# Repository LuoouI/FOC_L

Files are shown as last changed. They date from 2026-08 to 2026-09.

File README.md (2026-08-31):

# CYT

整套 CYT2BL3 FOC 电机驱动工程。

- `CYT/FOC_L/`：固件源码和底层工程
- `CYT/上位机/`：电机调试上位机
- `CYT/PCB/`：PCB 工程
- `CYT/电机调试台/`：调试台结构件
- `CYT/数据手册/`：芯片数据手册
- `CYT/上位机讲解视频/`：上位机讲解视频及在线播放地址

当前为开源实验版本。

项目采用 MIT License，第三方 SDK 和底层库仍遵循其各自许可证。

## 上位机讲解视频

[哔哩哔哩在线观看：基于 CYT2BL3 FOC 电机驱动项目开源，包含完整驱动代码、PCB、上位机、电机调试台、数据手册及讲解视频](https://www.bilibili.com/video/BV14Ytx69EH2)

[下载仓库中的上位机讲解原始视频](CYT/上位机讲解视频/上位机讲解%20.mp4)

## 电机调试台

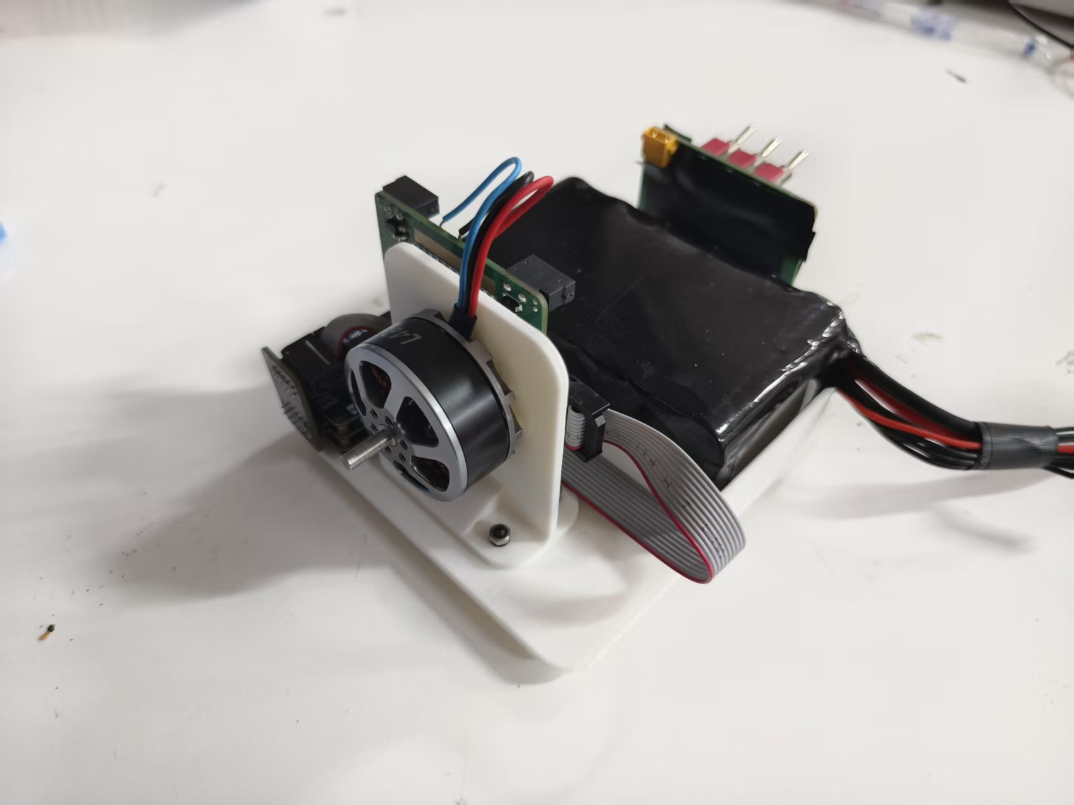
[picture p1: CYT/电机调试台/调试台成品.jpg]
电机调试台成品


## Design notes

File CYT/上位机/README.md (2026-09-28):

# FOC_L

用于当前 `FOC_L` 工程的 Windows 电机调试上位机。首版提供完整的仿真设备，可在下位机通信协议完成前检查工作流和界面。

## 已完成功能

- 电机连接、使能、停止、急停和急停复位
- 驱动板软件复位并自动重新同步设备参数
- 电压、电流/转矩、速度、位置四种控制模式
- 无感 FOC 的 HFI、SMO、PLL 参数分组，HFI 暂留，SMO/PLL 参数可在线调节
- 电流环、速度环、位置环和 SMO/PLL 使用可调边界滑块在线调参，滑块左右边界支持断电保存
- 开环、电流和速度目标使用可调边界滑块，位置目标使用首尾相接的圆盘实时给定，圆盘将 0° 与 360° 作为同一点，目标滑块边界支持断电保存
- 转速、电流、电压、角度、温度、PWM 等实时状态
- SMO 实际/估算 Iα、Iβ、Iq 误差、反电动势与 PLL 角度、角速度、相位误差示波器通道
- 示波器目标机械角度观测通道，可与实际机械角度对比
- 50000 点/通道环形缓冲示波器、按勾选通道订阅高速流、可见区峰谷抽稀、双点时间差测量、暂停显示和 CSV 导出
- 左侧菜单独立切换实时工作台和串口诊断
- Windows COM 口扫描、串口配置、协议帧过滤与手动发送
- 选择下位机内置乐曲并通过圆形播放按钮启动，播放完成后自动停止
- 事件和故障操作日志
- 控制、示波器和通道窗口根据可用空间自动调整尺寸，同时保留拖拽调整
- `Ctrl + +` 放大界面，`Ctrl + -` 缩小界面

## 启动

首次运行：

```powershell
cd "CYT\上位机"
npm install
npm run build
npm start
```

开发模式：

```powershell
npm run dev
```

仅在浏览器中预览界面：

```powershell
npm run dev:web
```

## 教学视频

上位机安装、串口连接和参数调试教学视频正在制作中，发布后补充链接。

## 当前限制

上位机通过 USB 转串口连接电机驱动板，CAN 留给 MCU 之间通信。串口协议实现位于 `electron/serial/protocol.cjs`，协议说明见 `docs/SERIAL_PROTOCOL.md`。当前下位机复用 `debug_init()` 的 UART0（460800 bit/s、P00_1/P00_0），连接期间不要在该串口输出 `printf` 文本。示波器全部已勾选设备通道固定 1 ms 采样，包括实际转速、实际 Iq、母线电压和机械角度；下位机在同一采样点读取所选字段，不再按字段数量自动降低采样率。当前波特率和 80% 带宽预算下最多允许同时勾选 8 个设备通道，超额选择或带宽不足的串口配置修改会被拒绝并提示。连接有效时电机失能仍保持采样，控制通信超时才暂停观测流。需要同步更新下位机固件；基础遥测仅更新状态卡，不作为已选设备通道的低速波形回退。

`foc_voice` 音乐模式负责选择下位机内置乐曲并发送播放命令。乐曲节拍和实际播放均由下位机负责；播放会话号用于防止 20 Hz 控制心跳重复触发歌曲，播放状态位用于在乐曲结束后自动关闭上位机使能。

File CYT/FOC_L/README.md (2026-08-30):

# FOC_L 固件

基于 CYT2BL3 的三相无刷电机 FOC 控制固件，包含电流环、速度环、位置环、SVPWM、电流采样、编码器反馈、参数存储和上位机通信。

## 目录

- `.vscode/`：IAR VS Code 辅助配置
- `libraries/`：CYT2BL3 SDK 和逐飞底层库
- `project/code/`：FOC、电机控制、采样、滤波和通信代码
- `project/user/`：主函数和中断入口
- `project/iar/`：IAR 工程配置

## 开发环境

- MCU：CYT2BL3
- IDE：IAR Embedded Workbench 9.40.1
- 工程入口：`project/iar/cyt2bl3.eww`

## 相关文档

- 固件模块说明：`project/code/驱动代码说明.md`
- 零点校准与三相自检提示音：`project/code/零点校准与三相自检提示音.md`
- TCPWM 和 ADC 触发链路：`project/code/FOC_TCPWM触发ADC采样链路.md`
- TCPWM、TriggerMux、ADC 术语：`project/code/FOC_TCPWM_ADC名词解释.md`

## 注意事项

本固件为个人实验和开发版本。首次上电应使用限流电源并进行空载测试，使用者需要根据实际功率器件和硬件设计确认过流、过压、欠压、过温及急停保护。

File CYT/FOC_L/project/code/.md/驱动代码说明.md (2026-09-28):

# CYT2BL3 FOC 电机驱动代码说明

## 1. 项目简介

本目录为基于 CYT2BL3 微控制器的三相无刷电机 FOC 驱动代码，主要用于电机控制算法验证、硬件调试和上位机联调。

当前代码包含以下功能：

- SVPWM 三相 PWM 输出
- Clarke/Park 变换及反变换
- 电流环、速度环和位置环控制
- 编码器角度采集、方向修正和零点校准
- ADC 电流采样及采样值校准
- 串口控制协议和运行状态回传
- 电机参数 Flash 保存
- 基于 FOC 的音乐播放实验功能

本项目当前属于实验和开发版本，使用前应先进行限流供电、空载测试和急停测试。

## 2. 目录结构

| 目录或文件 | 作用 |
|---|---|
| `Current_sample/` | 电流采样、采样值处理和校准 |
| `Fast_sin/` | 快速正弦和余弦计算 |
| `Filter/` | 滑动滤波器、AB 滤波器 |
| `Foc_transform/` | Clarke、Park 及反变换 |
| `Foc_Protocol/` | 上位机通信协议、帧解析和状态回传 |
| `Foc_voice/` | FOC 音乐模式和曲目播放 |
| `Function/` | 通用数学和辅助函数 |
| `Motor_Control/` | 电机状态机、三环控制和使能控制 |
| `Motor_Flash/` | 电机参数的 Flash 读写 |
| `Motor_Torque/` | 电流到估算转矩的换算 |
| `My_ADC/` | ADC 和触发链路初始化 |
| `My_TCPWM/` | PWM、TCPWM 和 ADC 触发配置 |
| `My_Key/` | 按键输入处理 |
| `My_LED/` | LED 状态指示 |
| `PID/` | PID 控制器实现 |
| `SVPWM/` | SVPWM 占空比计算和输出更新 |
| `My_Headfile.h` | 工程模块统一头文件 |
| `../user/main_cm4.c` | CM4 主函数和系统初始化 |
| `../user/cm4_isr.c` | CM4 中断服务函数 |

## 3. 控制流程

系统启动后，主函数依次完成 GPIO、ADC、TCPWM、PWM、编码器、Flash 参数和通信模块初始化。

电机运行时，PWM 中断负责高速控制任务：

1. 读取 ADC 电流采样值。
2. 进行电流偏置修正和坐标变换。
3. 执行电流环 PI 控制。
4. 根据控制模式执行速度环或位置环。
5. 计算电压矢量并生成 SVPWM 占空比。
6. 更新三相 PWM 输出和运行状态缓存。

通信接收和参数处理在较低优先级的主循环中执行，避免在高速控制中断中进行阻塞操作。

## 4. 控制模式

当前协议支持以下驱动模式：

| 模式 | 说明 |
|---|---|
| 开环模式 | 直接控制电压和电角度，适合初步检查相序和硬件输出 |
| 编码器 FOC | 使用编码器反馈进行电流、速度或位置控制 |
| 音乐模式 | 使用 FOC 产生设定频率和幅值的旋转磁场 |

有感 FOC 启动前应确认编码器方向、零点偏移、电流采样极性和电机相序均正确。

## 5. 参数说明

主要控制参数位于 `Motor_Control` 和 `Foc_Protocol` 模块中，包括：

- 电流环带宽
- 速度环 KP、KI
- 速度目标和速度斜坡
- 位置环 KP
- 位置角度死区和速度死区
- 位置环输出限幅
- AB 滤波器带宽
- 编码器零点偏移

电流环、速度环、位置环和观测器运行参数支持在线调整，下位机完成范围检查后在短临界区内整组应用。PWM 频率、死区和电机基础参数等硬件相关配置仍应在电机失能状态下修改；需要长期保存的参数应另行写入 Flash。

## 6. 通信接口

上位机默认通过 UART 连接驱动板，串口参数为：

- 波特率：460800 bit/s
- 数据位：8
- 校验位：无
- 停止位：1
- 多字节数据：小端序
- 浮点数：IEEE 754 单精度

完整帧格式和负载定义见上位机目录中的 `docs/SERIAL_PROTOCOL.md`。

控制帧包含使能、急停、控制模式、目标值和参数等信息。连续一段时间未收到合法控制帧时，驱动应关闭 PWM 输出。急停状态的优先级高于普通控制命令。

## 7. 调试建议

建议按照以下顺序进行调试：

1. 不连接电机，确认芯片能够正常启动和下载。
2. 检查三相 PWM 波形、频率、互补关系和死区时间。
3. 检查 ADC 触发时刻和电流采样偏置。
4. 低压限流条件下进行开环低幅值测试。
5. 检查编码器计数方向和机械角度变化。
6. 执行编码器零点校准。
7. 先调电流环，再调速度环，最后调位置环。
8. 逐步提高母线电压和目标转速。

## 8. 安全注意事项

- 首次上电必须使用限流电源，禁止直接接入未经确认的高压母线。
- 电机运行时应确保转子和负载不会造成人身伤害。
- 急停功能必须在实际硬件上验证，不能只依赖上位机按钮。
- 电流采样极性、编码器方向或电机相序错误时，不得继续提高电压和电流。
- 本代码未声明适用于人身安全、汽车、航空或其他安全关键设备。
- 使用者需要根据自己的功率器件、栅极驱动器和电源结构补充过流、过压、欠压、过温和硬件关断保护。

## 9. 当前限制

- 工程依赖对应芯片 SDK 和第三方底层库，具体版本需要根据本地开发环境配置。
- 当前目录主要保存控制源码，完整 IDE 工程配置和生成文件可能未随源码发布。
- 不同电机、电流采样电路和编码器需要重新校准参数。
- 参数默认值仅用于当前实验硬件，不代表通用电机配置。
- 代码和通信协议仍可能发生变化，当前版本不保证向后兼容。

## 10. 开源说明

本代码仅供学习、研究和实验使用。使用、修改或分发前，请分别确认芯片 SDK、底层库、示例代码和其他第三方文件的授权范围。项目许可证以仓库根目录中的 `LICENSE` 文件为准。

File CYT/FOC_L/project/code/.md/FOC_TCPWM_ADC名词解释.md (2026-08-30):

# CYT2BL3 FOC：TCPWM、TriggerMux 与 ADC 名词解释

## 1. 整体理解

在本工程中，各模块的分工可以先这样理解：

```text
TCPWM：决定什么时候采样
TriggerMux：决定触发信号送到哪里
PASS：管理模拟输入、ADC 和 ADC 触发
SAR：真正完成模拟量采样和模数转换
ADC 中断：通知 CPU 数据已经转换完成
```

可以把它类比成：

```text
TCPWM            = 闹钟
tr_out1          = 闹钟输出线
TriggerMux       = 电话交换机
PASS Generic0    = 广播频道
SAR0/SAR1/SAR2   = 三台 ADC 转换机器
ADC Channel      = 每台机器需要采集的具体输入
Group Done       = 本次采集任务全部完成的通知
```

完整链路为：

```text
TCPWM CC1 Match
    ↓
TCPWM tr_out1
    ↓
PERI TriggerMux
    ↓
PASS Generic Trigger
    ↓
SAR ADC Channel
    ↓
采样和转换
    ↓
Group Done
    ↓
FOC 电流环
```

---

## 2. 三种不同的 Group

这里出现了三种完全不同的 Group，不能混为一谈。

### 2.1 TCPWM Group

表示 TCPWM 计数器的硬件分组：

| TCPWM Group | 功能 |
| --- | --- |
| Group0 | 普通 16 位定时器组 |
| Group1 | 带电机控制功能的 16 位定时器组 |
| Group2 | 32 位定时器组 |

FOC 一般优先使用 Group1。

### 2.2 TriggerMux Group

表示触发路由硬件的分组。每组支持的触发来源和目标不同。

当前方案使用 TriggerMux Group6，是因为该组可以选择 TCPWM Group1 的 `tr_out1`，并把它送到 PASS 通用触发输入。

### 2.3 ADC Group

表示一次 ADC 触发后需要顺序转换的一组通道。

例如同一个 SAR 顺序采集三个通道：

```text
CH0：组首，直接接收硬件触发
CH1：不直接接收硬件触发
CH2：组尾，转换完成后产生 Group Done
```

三种 Group 之间没有编号对应关系。

---

## 3. TCPWM

TCPWM 可以理解为 Timer、Counter、PWM 的组合外设。

它可以完成：

- 定时
- 计数
- PWM 输出
- 编码器计数
- 输入捕获
- 产生其他外设的硬件触发

在 FOC 中，TCPWM 主要负责：

```text
1. 产生 U、V、W 三相互补 PWM
2. 在指定 PWM 位置触发 ADC
```

---

## 4. TCPWM0_GRP1_CNT0

```c
TCPWM0_GRP1_CNT0
```

拆开理解：

```text
TCPWM0：第 0 个 TCPWM 外设
GRP1：TCPWM 的电机控制计数器组
CNT0：Group1 中第 0 个计数器
```

FOC 三相 PWM 可以使用：

```text
TCPWM0_GRP1_CNT0：U 相
TCPWM0_GRP1_CNT1：V 相
TCPWM0_GRP1_CNT2：W 相
```

三个计数器必须同步计数和同步启动。

---

## 5. COUNTER

`COUNTER` 是计数器当前值。

中心对齐 PWM 的计数过程为：

```text
0 → PERIOD → 0 → PERIOD → 0
```

例如：

```text
PERIOD = 4000
```

计数过程为：

```text
0, 1, 2 ... 3999, 4000, 3999 ... 2, 1, 0
```

一次向上计数加一次向下计数，构成一个完整的中心对齐 PWM 周期。

---

## 6. PERIOD

`PERIOD` 是计数器的顶部值。

中心对齐 PWM 频率近似为：

```text
PWM 频率 = TCPWM 计数时钟 / (2 × PERIOD)
```

实际计算还需要考虑：

- TCPWM 输入时钟
- TCPWM 内部分频器
- PERIOD 是否包含计数端点

---

## 7. CC0 与 CC1

`CC` 表示 Compare/Capture，即比较/捕获寄存器。

PWM 模式主要使用比较功能。

### 7.1 CC0

`CC0` 通常控制 PWM 占空比。

```text
COUNTER == CC0
        ↓
产生 CC0 Match
        ↓
根据 TR_PWM_CTRL 改变 PWM 输出
```

在 FOC 中：

```text
U 相 CC0：U 相占空比
V 相 CC0：V 相占空比
W 相 CC0：W 相占空比
```

SVPWM 最终计算的就是三个 CC0 值。

### 7.2 CC1

`CC1` 是第二个独立比较点。

它可以只产生事件，不改变 PWM 输出，因此适合设置 ADC 采样时刻。

```text
COUNTER == CC1
        ↓
产生 CC1 Match
        ↓
通过 tr_out1 触发 ADC
```

建议配置：

```c
Pwm_config.cc1MatchMode = CY_TCPWM_PWM_TR_CTRL2_NO_CHANGE;
```

含义是 CC1 匹配时不改变 PWM 输出，只用于产生内部事件。

---

## 8. CC1_MATCH_UP_EN 与 CC1_MATCH_DOWN_EN

中心对齐模式会在向上计数和向下计数时各经过一次 CC1。

如果两个方向都允许：

```text
一个完整 PWM 周期产生两次 CC1 Match
```

如果每个完整 PWM 周期只想采样一次，可以只允许向上计数匹配：

```c
TCPWM0_GRP1_CNT0->unCTRL.stcField.u1CC1_MATCH_UP_EN   = 1u;
TCPWM0_GRP1_CNT0->unCTRL.stcField.u1CC1_MATCH_DOWN_EN = 0u;
```

如果需要一个周期采样两次，则两个方向都可以打开。

`CC0_MATCH_UP_EN` 和 `CC0_MATCH_DOWN_EN` 同理，只是它们控制 CC0 比较事件。

---

## 9. Overflow

`Overflow` 表示计数器到达顶部边界产生的事件。

中心对齐模式下可以理解为：

```text
3998 → 3999 → 4000 → 3999 → 3998
                  ↑
               Overflow
```

此时计数方向由向上变为向下。

---

## 10. Underflow

`Underflow` 表示计数器到达底部边界产生的事件。

```text
2 → 1 → 0 → 1 → 2
        ↑
    Underflow
```

此时计数方向由向下变为向上。

---

## 11. Terminal Count

`Terminal Count` 简称 `TC`，表示当前计数模式定义的周期终点。

它不一定永远等于 Overflow。

对于：

```c
CY_TCPWM_COUNTER_COUNT_UP_DOWN1
```

SDK 说明只在 Underflow 时产生 Terminal Count。因此可以把它理解为：

```text
一次完整的向上、向下计数结束
```

使用 TC 触发 ADC，一般每个完整 PWM 周期触发一次。

使用 CC1 则可以自由调整具体采样位置。

---

## 12. Match

`Match` 表示比较相等。

例如：

```text
COUNTER = 200
CC1     = 200
```

此时产生 `CC1 Match`。

Match 本身只是内部事件。它是否改变 PWM、产生中断或产生外设触发，由其他寄存器决定。

---

## 13. tr、tr_in 与 tr_out

`tr` 是 Trigger，即触发。

### 13.1 tr_out

`tr_out` 是某个外设产生的触发输出。

例如：

```text
TCPWM tr_out1
```

表示 TCPWM 的第 1 路触发输出。

### 13.2 tr_in

`tr_in` 是某个外设接收的触发输入。

例如：

```text
PASS tr_sar_gen_in[0]
```

表示 PASS 的 SAR 通用触发输入 0。

信号方向为：

```text
TCPWM tr_out1 → PASS tr_in
```

---

## 14. tr_out0 与 tr_out1

每个 TCPWM 计数器可以提供两路触发输出：

```text
tr_out0
tr_out1
```

两路输出可以选择不同的内部事件，例如：

```text
tr_out0 = Terminal Count
tr_out1 = CC1 Match
```

本 FOC 方案建议：

```text
tr_out1 = CC1 Match
```

---

## 15. TR_OUT_SEL

`TR_OUT_SEL` 是 Trigger Output Select，即触发输出选择寄存器。

它决定：

```text
什么内部事件产生 tr_out0
什么内部事件产生 tr_out1
```

例如：

```c
Pwm_config.trigger1EventCfg = CY_TCPWM_COUNTER_CC1_MATCH;
```

对应：

```text
TR_OUT_SEL.OUT1 = CC1_MATCH
```

因此形成：

```text
CC1 Match → tr_out1
```

---

## 16. TriggerMux

`Mux` 是 Multiplexer，即多路选择器。

TriggerMux 的作用是从多个触发来源中选择一个，送到指定外设的触发输入。

```text
                 ┌─ TCPWM CNT0 tr_out1
                 ├─ TCPWM CNT1 tr_out1
PASS Generic0 ←──┼─ DMA tr_out
                 ├─ GPIO trigger
                 └─ Event Generator
```

TriggerMux 不负责产生采样时刻，它只负责连接和路由。

---

## 17. TriggerMux Group6

TriggerMux 内部有很多路由分组，每组支持不同的来源和目标。

当前方案使用 Group6：

```text
TCPWM Group1 CNT0 tr_out1
        ↓
TriggerMux Group6
        ↓
PASS Generic Trigger 0
```

`TriggerMux Group6` 与 `TCPWM Group1` 没有编号对应关系。

---

## 18. TRIG_IN_MUX_6_TCPWM_16M_TR_OUT10

```c
TRIG_IN_MUX_6_TCPWM_16M_TR_OUT10
```

拆开理解：

```text
TRIG_IN：TriggerMux 的输入候选信号
MUX_6：属于 TriggerMux Group6
TCPWM_16M：来源是 TCPWM 的 16 位电机控制计数器组
TR_OUT10：tr_out1[0]，即输出1、计数器0
```

需要特别注意：

```text
16M 中的 M 表示 Motor，不是 MHz
```

`TR_OUT10` 不是“第十号输出”，而是：

```text
TR_OUT1 + counter 0
```

类似地：

```text
TR_OUT11  = tr_out1[1]
TR_OUT12  = tr_out1[2]
TR_OUT110 = tr_out1[10]
```

---

## 19. TRIG_OUT_MUX_6_PASS_GEN_TR_IN0

```c
TRIG_OUT_MUX_6_PASS_GEN_TR_IN0
```

拆开理解：

```text
TRIG_OUT：TriggerMux 的输出目标
MUX_6：属于 TriggerMux Group6
PASS_GEN：目标是 PASS 通用触发模块
TR_IN0：PASS 通用触发输入0
```

因此下面的连接：

```c
Cy_TrigMux_Connect(
    TRIG_IN_MUX_6_TCPWM_16M_TR_OUT10,
    TRIG_OUT_MUX_6_PASS_GEN_TR_IN0,
    CY_TR_MUX_TR_INV_DISABLE,
    TRIGGER_TYPE_EDGE,
    0u);
```

可以翻译为：

```text
把 TCPWM Group1 CNT0 的 tr_out1
连接到 PASS 通用触发输入0
```

---

## 20. PERI

`PERI` 可以理解为芯片的外设基础设施模块。

它管理：

- TriggerMux
- 外设公共时钟
- 软件触发命令
- 一部分外设访问和控制功能

TCPWM 和 ADC 是功能外设，PERI 负责把它们连接起来。

---

## 21. One-to-One

`One-to-One` 是一对一固定专线。

它表示：

```text
一个固定触发来源 → 一个固定触发目标
```

软件可以设置：

- 是否打开专线
- 是否反相
- 使用边沿还是电平
- 调试时是否冻结

但不能改变专线两端。

例如：

```text
TCPWM Group1 CNT0 tr_out1 → SAR0 CH0
```

不能通过配置把它改成：

```text
TCPWM Group1 CNT0 tr_out1 → SAR1 CH4
```

---

## 22. PASS

PASS 可以理解为芯片的可编程模拟子系统。

它包含或管理：

- SAR ADC
- 模拟输入选择
- ADC 通道配置
- ADC 触发输入
- ADC 结果和状态
- ADC 中断

链路中的位置为：

```text
TriggerMux → PASS trigger input → SAR ADC
```

---

## 23. PASS0_EPASS_MMIO

`MMIO` 表示 Memory-Mapped I/O，即存储器映射寄存器。

```c
PASS0_EPASS_MMIO
```

表示 PASS0 的扩展配置寄存器区域。

例如：

```c
Cy_Adc_SetGenericTriggerInput(PASS0_EPASS_MMIO, 0u, 0u, 0u);
```

实际上是在配置该 SAR 的 `PASS_SAR_TR_IN_SEL` 寄存器。

---

## 24. SAR ADC

`SAR` 是 Successive Approximation Register，即逐次逼近型 ADC。
    
它通过逐位比较，把模拟电压转换成数字结果。

本芯片有三套独立的 SAR：

```text
SAR0
SAR1
SAR2
```

因此：

```text
SAR0 一个通道
SAR1 一个通道
SAR2 一个通道
```

可以并行采样和转换。

但：

```text
SAR0 CH0
SAR0 CH1
SAR0 CH2
```

仍然共用一套 SAR0 转换核心，只能依次转换。

---

## 25. ADC Channel

ADC Channel 是 SAR 内的一份通道配置，不等于一台独立 ADC。

每个通道保存自己的：

- 模拟输入地址
- 采样时间
- 触发源
- 优先级
- 结果处理方式
- 中断配置

例如：

```text
SAR0：一台 ADC 转换器
SAR0 CH0：SAR0 的第0个通道配置
SAR0 CH1：SAR0 的第1个通道配置
```

---

## 26. pinAddress

`pinAddress` 表示 SAR 内部需要采集的模拟输入编号。

需要区分：

```text
ADC Channel：通道配置槽
pinAddress：该配置槽选择的实际模拟输入
```

二者经常使用相同编号，但概念并不相同。

---

## 27. tr_sar_ch_in

`tr_sar_ch_in` 是 SAR Channel 的专用触发输入。

它用于一对一触发链路：

```text
TCPWM tr_out1
    ↓
PERI One-to-One
    ↓
PASS tr_sar_ch_in
    ↓
固定 ADC Channel
```

ADC 通道配置为：

```c
Adc_channel_config.triggerSelection = CY_ADC_TRIGGER_TCPWM;
```

就是监听这条专用触发输入。

---

## 28. tr_sar_gen_in

`gen` 是 Generic，即通用。

`tr_sar_gen_in` 是 PASS 的通用 SAR 触发输入，例如：

```text
tr_sar_gen_in[0]
```

它不是某个固定 ADC 通道的专线，而是一条可以再分配给 SAR0、SAR1、SAR2 的通用触发线。

---

## 29. GENERIC0~4

每个 SAR 内部有多个通用触发选择入口：

```text
GENERIC0
GENERIC1
GENERIC2
GENERIC3
GENERIC4
```

`GENERIC0` 不一定永远连接 PASS 通用触发线0。

具体连接关系由 `PASS_SAR_TR_IN_SEL.IN0_SEL` 决定。

例如：

```c
Cy_Adc_SetGenericTriggerInput(PASS0_EPASS_MMIO, 1u, 0u, 3u);
```

表示：

```text
SAR1 的 GENERIC0 ← PASS 通用触发线3
```

参数依次为：

```text
PASS 实例、SAR 编号、GENERIC 编号、PASS 通用触发线编号
```

---

## 30. SEL

`SEL` 是 Select，即选择。

`PASS_SAR_CH_TR_CTL.SEL` 决定 ADC 通道使用哪个触发源：

| SEL | SDK 枚举 | 含义 |
| ---: | --- | --- |
| 0 | `CY_ADC_TRIGGER_OFF` | 不直接接收外部触发 |
| 1 | `CY_ADC_TRIGGER_TCPWM` | 一对一 TCPWM 触发 |
| 2 | `CY_ADC_TRIGGER_GENERIC0` | 通用触发0 |
| 3 | `CY_ADC_TRIGGER_GENERIC1` | 通用触发1 |
| 4 | `CY_ADC_TRIGGER_GENERIC2` | 通用触发2 |
| 5 | `CY_ADC_TRIGGER_GENERIC3` | 通用触发3 |
| 6 | `CY_ADC_TRIGGER_GENERIC4` | 通用触发4 |
| 7 | `CY_ADC_TRIGGER_CONTINUOUS` | 连续触发 |

---

## 31. CY_ADC_TRIGGER_OFF

`CY_ADC_TRIGGER_OFF` 不一定表示通道永远不转换。

在同一个 SAR 的通道组中，它通常表示：

```text
这个通道不直接接收硬件触发
由组内前一个通道带着继续转换
```

例如：

```text
CH0：GENERIC0，组首
CH1：OFF
CH2：OFF，isGroupEnd=true
```

一次触发后的顺序为：

```text
CH0 → CH1 → CH2 → Group Done
```

---

## 32. isGroupEnd

`isGroupEnd` 表示该通道是不是当前 ADC 转换组的最后一个通道。

例如：

```text
CH0：isGroupEnd=false
CH1：isGroupEnd=false
CH2：isGroupEnd=true
```

CH2 转换完成后，本组结束并可以产生 Group Done。

如果某个 SAR 只采一个电流通道，该通道本身就是组首和组尾：

```c
Adc_channel_config.isGroupEnd = true;
```

---

## 33. Group Done

`Group Done` 表示一个 ADC 转换组已经全部完成。

```text
PWM 触发
   ↓
组内 ADC 通道全部转换
   ↓
Group Done
   ↓
进入 ADC 中断
   ↓
读取电流并执行 FOC
```

配置：

```c
Adc_channel_config.mask.grpDone = true;
```

---

## 34. Edge Trigger

边沿触发只关心信号发生跳变的瞬间。

```text
低电平 → 高电平
         ↑
       触发一次
```

当前使用：

```c
TRIGGER_TYPE_EDGE
```

它适合 ADC 启动、DMA 请求等单次硬件事件。

TriggerMux 会把触发同步到接收外设时钟域，并形成接收时钟域内的触发脉冲。

---

## 35. Level Trigger

电平触发表示只要信号保持有效电平，触发条件就一直存在。

```text
________████████████________
        整段时间有效
```

ADC 周期启动通常优先使用 Edge，避免有效电平保持期间形成持续请求。

---

## 36. Trigger Synchronization

TCPWM 和 PASS/SAR 可能处于不同的时钟域。

TriggerMux 需要进行同步：

```text
TCPWM 时钟域
      ↓
触发同步器
      ↓
PASS/SAR 时钟域
```

所以 ADC 真正开始采样的时刻相对于 CC1 会有固定的时钟延迟。

这个延迟一般是确定的，可以通过调整 CC1 进行补偿。

---

## 37. Sample 与 Conversion

### 37.1 Sample

采样阶段是 ADC 内部采样电容连接模拟输入：

```text
模拟输入 → 采样电容
```

采样时间由：

```c
Adc_channel_config.sampleTime
```

决定。

### 37.2 Conversion

采样结束后，SAR 才开始逐次逼近转换：

```text
采样电压 → SAR 逐位比较 → 数字结果
```

完整时序为：

```text
CC1 Trigger
    ↓
触发同步延迟
    ↓
ADC Sample
    ↓
SAR Conversion
    ↓
Result Valid / Group Done
    ↓
CPU 读取结果
```

触发时刻和 ADC 结果产生时刻不是同一个时刻。

---

## 38. 一对一触发链路翻译

```text
TCPWM Group1 CNT0
    ↓ CC1 Match
TCPWM tr_out1[256]
    ↓
PERI One-to-One
    ↓
PASS tr_sar_ch_in[0]
    ↓
SAR0 CH0，SEL=TCPWM
    ↓
ADC 采样和转换
```

翻译成人话：

> PWM 主计数器运行到 CC1 时产生事件，这个事件经过芯片内部固定专线送到 SAR0 CH0，SAR0 CH0 随即开始采样。

---

## 39. 通用触发链路翻译

```text
TCPWM Group1 CNT0
    ↓ CC1 Match
TCPWM tr_out1[256]
    ↓
TriggerMux Group6
    ↓
PASS tr_sar_gen_in[0]
    ↓
SAR0/SAR1/SAR2 GENERIC0
    ↓
各 SAR 的 ADC Channel
    ↓
ADC 采样和转换
```

翻译成人话：

> PWM 主计数器运行到 CC1 时产生事件。TriggerMux 把这个事件送到 PASS 通用触发线0。SAR0、SAR1、SAR2都监听这条线，因此三套 ADC 可以在同一个 PWM 时刻开始采样。

---

## 40. 常见缩写速查表

| 缩写 | 含义 |
| --- | --- |
| TCPWM | Timer/Counter/PWM 外设 |
| CNT | Counter，计数器 |
| GRP | Group，硬件分组 |
| CC | Compare/Capture，比较/捕获 |
| TC | Terminal Count，周期终点事件 |
| TR | Trigger，触发 |
| IN | Input，输入 |
| OUT | Output，输出 |
| MUX | Multiplexer，多路选择器 |
| SEL | Select，选择 |
| CTL | Control，控制 |
| CMD | Command，命令 |
| INTR | Interrupt，中断 |
| CH | Channel，通道 |
| GEN | Generic，通用 |
| PASS | 可编程模拟子系统 |
| SAR | Successive Approximation Register ADC |
| MMIO | Memory-Mapped I/O，存储器映射寄存器 |
| PCLK | Peripheral Clock，外设时钟 |
| PWM | Pulse Width Modulation，脉宽调制 |

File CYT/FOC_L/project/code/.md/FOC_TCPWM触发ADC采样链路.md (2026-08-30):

# CYT2BL3 FOC：TCPWM 触发 ADC 采样链路

## 1. 先给结论

这颗 CYT2BL3（TRAVEO T2G TVII-B-H-4M）有两种可用的 TCPWM 触发 ADC 方式：

1. **TCPWM 到 ADC 通道的一对一专用触发**
   - 链路短，配置简单。
   - TCPWM 通道和 SAR 通道的对应关系固定。
   - ADC 通道配置为 `CY_ADC_TRIGGER_TCPWM`。

2. **TCPWM 经过 TriggerMux，进入 PASS 通用触发输入**
   - ADC 引脚和通道选择更自由。
   - 一个主 PWM 触发源可以同时送给 SAR0、SAR1、SAR2。
   - 更适合 FOC 的多路同步电流采样。
   - ADC 通道配置为 `CY_ADC_TRIGGER_GENERIC0`。

本工程建议先使用第 2 种：**主 PWM 的 CC1 匹配事件 -> TCPWM tr_out1 -> TriggerMux Group 6 -> PASS generic trigger 0 -> SAR0/SAR1/SAR2 -> ADC 转换完成中断 -> FOC 电流环**。

```mermaid
flowchart LR
    A["TCPWM0 Group1 主 PWM 计数器"] --> B["CC1 匹配事件"]
    B --> C["TCPWM tr_out1"]
    C --> D["PERI TriggerMux Group 6"]
    D --> E["PASS tr_sar_gen_in 0"]
    E --> F["SAR0 GENERIC0"]
    E --> G["SAR1 GENERIC0"]
    E --> H["SAR2 GENERIC0"]
    F --> I["电流 ADC 结果"]
    G --> I
    H --> I
    I --> J["ADC 完成中断 / FOC 电流环"]
```

---

## 2. 数据手册中的关键寄存器

数据手册：`CYT/数据手册/原文.pdf`。

| PDF 页码 | 寄存器 | 作用 |
| --- | --- | --- |
| 1578 | `PASS_SAR_CH_TR_CTL` | ADC 通道选择软件、TCPWM、GENERIC0 等触发源 |
| 1596 | `PASS_SAR_TR_IN_SEL` | 每个 SAR 的 GENERIC0~4 从 PASS 通用触发线中选择一路 |
| 1616 | `PERI_TR_1TO1_GR_TR_CTL` | 打开 TCPWM 到 ADC 通道的一对一专用触发 |
| 2468~2469 | `TCPWM_GRP_CNT_CTRL` | 控制 CC0/CC1 在向上、向下计数时是否产生匹配事件 |
| 2496 | `TCPWM_GRP_CNT_TR_OUT_SEL` | 选择 `tr_out0`、`tr_out1` 由哪个内部事件产生 |

`TCPWM_GRP_CNT_TR_OUT_SEL.OUT1` 可以选择：

- `OVERFLOW`
- `UNDERFLOW`
- `TC`，即 Terminal Count
- `CC0_MATCH`
- `CC1_MATCH`
- `LINE_OUT`
- `DISABLED`

SDK 中对应枚举为：

```c
CY_TCPWM_COUNTER_OVERFLOW
CY_TCPWM_COUNTER_UNDERFLOW
CY_TCPWM_COUNTER_TERMINAL_COUNT
CY_TCPWM_COUNTER_CC0_MATCH
CY_TCPWM_COUNTER_CC1_MATCH
CY_TCPWM_COUNTER_LINE_OUT
CY_TCPWM_COUNTER_DISABLED
```

这些枚举均已在当前工程的 `cy_tcpwm.h` 中确认存在。

---

## 3. 为什么建议用 CC1 作为 ADC 采样定时点

FOC 的三相占空比一般由 `CC0` 控制，因此不要拿 `CC0_MATCH` 直接作为固定 ADC 采样点，否则采样时刻会跟着占空比变化，容易刚好落到 MOS 管切换和电流尖峰附近。

Group1 电机控制 TCPWM 还有独立的 `CC1`：

- `CC0`：控制 PWM 占空比。
- `CC1`：单独安排 ADC 采样时刻。
- `trigger1EventCfg = CY_TCPWM_COUNTER_CC1_MATCH`：CC1 匹配时产生 `tr_out1`。
- `cc1MatchMode = CY_TCPWM_PWM_TR_CTRL2_NO_CHANGE`：CC1 只产生事件，不改变 PWM 输出。

中心对齐 PWM 的计数过程为：

```text
0 -> PERIOD -> 0 -> PERIOD -> 0 ...
```

如果 CC1 的上下计数匹配都打开，一个完整 PWM 周期会产生两次触发。只想每个 PWM 周期采样一次时，可只打开一个方向：

```c
TCPWM0_GRP1_CNT0->unCTRL.stcField.u1CC1_MATCH_UP_EN   = 1u;
TCPWM0_GRP1_CNT0->unCTRL.stcField.u1CC1_MATCH_DOWN_EN = 0u;
```

这样 ADC 每个完整的中心对齐 PWM 周期只触发一次，并且采样点由 `CC1` 决定。

### 推荐的第一版采样点

对于三电阻低侧采样，可先把采样点放在计数器从 0 向上计数后的一个小延时位置：

```text
CC1 = 死区时间对应计数值 + 运放建立时间对应计数值 + 安全余量
```

不要一开始就把 CC1 写成 0。虽然计数器底部通常是低侧导通区，但 ADC、运放和开关节点需要一定建立时间。

如果使用母线单电阻、双电阻重构或采样窗口会随扇区改变，则 CC1 需要由 SVPWM 扇区和有效矢量时间动态计算，不能一直使用固定值。

---

## 4. 推荐链路：通用触发广播

以下示例使用：

- 主定时器：`TCPWM0_GRP1_CNT0`
- 主定时器输出触发：`tr_out1[256]`
- TriggerMux 输入：`TRIG_IN_MUX_6_TCPWM_16M_TR_OUT10`
- PASS 通用触发线：`TRIG_OUT_MUX_6_PASS_GEN_TR_IN0`
- SAR0/SAR1/SAR2 的 `GENERIC0` 都选择 PASS 通用触发线 0

注意 `TR_OUT10` 的名称含义是 **tr_out1 + counter 0**，不是十号输出。

### 4.1 TCPWM 配置关键项

```c
cy_stc_tcpwm_pwm_config_t Pwm_config;

memset(&Pwm_config, 0, sizeof(Pwm_config));

Pwm_config.pwmMode          = CY_TCPWM_PWM_MODE_DEADTIME;
Pwm_config.countDirection   = CY_TCPWM_COUNTER_COUNT_UP_DOWN1;
Pwm_config.runMode          = CY_TCPWM_PWM_CONTINUOUS;
Pwm_config.period           = FOC_PWM_PERIOD_COUNT;
Pwm_config.compare0         = FOC_PWM_PERIOD_COUNT / 2u;
Pwm_config.compare1         = FOC_ADC_SAMPLE_COUNT;
Pwm_config.cc0MatchMode     = CY_TCPWM_PWM_TR_CTRL2_INVERT;
Pwm_config.cc1MatchMode     = CY_TCPWM_PWM_TR_CTRL2_NO_CHANGE;
Pwm_config.overflowMode     = CY_TCPWM_PWM_TR_CTRL2_SET;
Pwm_config.underflowMode    = CY_TCPWM_PWM_TR_CTRL2_CLEAR;
Pwm_config.trigger0EventCfg = CY_TCPWM_COUNTER_TERMINAL_COUNT;
Pwm_config.trigger1EventCfg = CY_TCPWM_COUNTER_CC1_MATCH;

Cy_Tcpwm_Pwm_Init(TCPWM0_GRP1_CNT0, &Pwm_config);
```

`FOC_PWM_PERIOD_COUNT` 和 `FOC_ADC_SAMPLE_COUNT` 属于工程级固定参数，按你的代码规范放进 `My_TCPWM.h`。

### 4.2 修正比较事件方向使能

当前工程所带的 `Cy_Tcpwm_Pwm_Init()` 使用一个清零后的 `CTRL` 临时变量，但没有给下面四个匹配使能位赋值：

- `CC0_MATCH_UP_EN`
- `CC0_MATCH_DOWN_EN`
- `CC1_MATCH_UP_EN`
- `CC1_MATCH_DOWN_EN`

而数据手册给出的复位默认值是 1。因此调用初始化函数后，建议显式写回：

```c
TCPWM0_GRP1_CNT0->unCTRL.stcField.u1CC0_MATCH_UP_EN   = 1u;
TCPWM0_GRP1_CNT0->unCTRL.stcField.u1CC0_MATCH_DOWN_EN = 1u;
TCPWM0_GRP1_CNT0->unCTRL.stcField.u1CC1_MATCH_UP_EN   = 1u;
TCPWM0_GRP1_CNT0->unCTRL.stcField.u1CC1_MATCH_DOWN_EN = 0u;
```

如果三相 PWM 使用 Group1 CNT0、CNT1、CNT2，这些位需要给三个计数器分别配置。三相计数器还必须同步启动，不能把三个独立的软件启动调用当成严格同步。

### 4.3 TriggerMux 路由

这里输入和输出都属于 TriggerMux Group 6，因此只需要调用一次 `Cy_TrigMux_Connect()`，不需要走两级跨组连接。

```c
cy_en_trigmux_status_t Trigger_status;

Trigger_status = Cy_TrigMux_Connect(
    TRIG_IN_MUX_6_TCPWM_16M_TR_OUT10,
    TRIG_OUT_MUX_6_PASS_GEN_TR_IN0,
    CY_TR_MUX_TR_INV_DISABLE,
    TRIGGER_TYPE_EDGE,
    0u);
```

`TRIGGER_TYPE_EDGE` 会在接收外设时钟域内同步触发，并形成两周期脉冲，适合作为 ADC 启动事件。

初始化代码必须检查 `Trigger_status == CY_TRIGMUX_SUCCESS`，不能忽略连接失败。

### 4.4 三相占空比硬件同步

主计数器的 `tr_out0[256]` 输出 TC 事件，通过 TriggerMux 接到 TCPWM 公共输入 1：

```c
(void)Cy_TrigMux_Connect(
    TRIG_IN_MUX_4_TCPWM_16M_TR_OUT00,
    TRIG_OUT_MUX_4_TCPWM_ALL_CNT_TR_IN1,
    CY_TR_MUX_TR_INV_DISABLE,
    TRIGGER_TYPE_EDGE,
    0u);
```

公共输入 1 对应各 TCPWM 计数器的 `TRIG4`。三相 PWM 将 Compare0 Swap 输入配置为 `TRIG4` 上升沿后，`My_TCPWM_SetDuty()` 只需写入三相 `CC0_BUFF`，主计数器每次产生 TC 事件时便会由硬件同步交换三相 `CC0` 与 `CC0_BUFF`。

该机制是交换而不是单向装载。控制环必须在每个 PWM 周期都写入三相占空比，即使占空比未变化也不能跳过；否则新旧比较值可能在后续周期交替生效。

### 4.5 让三个 SAR 的 GENERIC0 都选择通用触发线 0

```c
Cy_Adc_SetGenericTriggerInput(PASS0_EPASS_MMIO, 0u, 0u, 0u);
Cy_Adc_SetGenericTriggerInput(PASS0_EPASS_MMIO, 1u, 0u, 0u);
Cy_Adc_SetGenericTriggerInput(PASS0_EPASS_MMIO, 2u, 0u, 0u);
```

参数依次为：

```text
PASS 实例、SAR 编号、SAR 内部 GENERIC 编号、PASS 通用触发线编号
```

三行代码表示：

- SAR0 的 GENERIC0 <- PASS generic trigger 0
- SAR1 的 GENERIC0 <- PASS generic trigger 0
- SAR2 的 GENERIC0 <- PASS generic trigger 0

因此一次主 PWM 触发可以让三个 SAR 同时开始各自的转换。

### 4.6 ADC 通道配置

ADC 通道初始化时把触发源改成 `CY_ADC_TRIGGER_GENERIC0`：

```c
cy_stc_adc_channel_config_t Adc_channel_config;

memset(&Adc_channel_config, 0, sizeof(Adc_channel_config));

Adc_channel_config.triggerSelection = CY_ADC_TRIGGER_GENERIC0;
Adc_channel_config.channelPriority  = 0u;
Adc_channel_config.preenptionType   = CY_ADC_PREEMPTION_FINISH_RESUME;
Adc_channel_config.pinAddress       = Current_pin_address;
Adc_channel_config.sampleTime       = Current_sample_count;
Adc_channel_config.isGroupEnd       = true;
Adc_channel_config.mask.grpDone     = true;

Cy_Adc_Channel_Init(Current_adc_channel, &Adc_channel_config);
Cy_Adc_Channel_Enable(Current_adc_channel);
```

其中 `Current_adc_channel` 和 `Current_pin_address` 必须根据最终电流采样引脚填写。它们不是 SDK 中现成的变量名，只是说明此处需要传入实际通道，例如：

```c
PASS0_SAR0_CH0
PASS0_SAR1_CH4
PASS0_SAR2_CH4
```

对应的 `pinAddress` 分别应填写真实 SAR 通道号。配置硬件触发后，不要再调用 `Cy_Adc_Channel_SoftwareTrigger()` 启动周期采样。

数据手册还要求：修改 `PASS_SAR_CH_TR_CTL` 前，必须先禁用该 ADC 通道或禁用 SAR IP。

---

## 5. 一对一专用触发链路

固定通道正好匹配时，可以使用专用线路：

```mermaid
flowchart LR
    A["TCPWM tr_out1 固定通道"] --> B["PERI 1-to-1 Trigger"]
    B --> C["PASS tr_sar_ch_in 固定通道"]
    C --> D["ADC 通道 SEL = TCPWM"]
```

例如 TCPWM Group1 CNT0 的 `tr_out1[256]` 固定连接到 SAR0 CH0：

```c
Cy_TrigMux_Connect1To1(
    TRIG_OUT_1TO1_1_TCPWM_TO_PASS_CH_TR0,
    CY_TR_MUX_TR_INV_DISABLE,
    TRIGGER_TYPE_EDGE,
    0u);

Adc_channel_config.triggerSelection = CY_ADC_TRIGGER_TCPWM;
```

Group1 电机控制计数器与 ADC 通道的前四组对应关系如下：

| TCPWM Group1 计数器 | 固定 ADC 通道 |
| --- | --- |
| CNT0 | SAR0 CH0 |
| CNT1 | SAR1 CH0 |
| CNT2 | SAR2 CH0 |
| CNT3 | SAR0 CH1 |
| CNT4 | SAR1 CH1 |
| CNT5 | SAR2 CH1 |
| CNT6 | SAR0 CH2 |
| CNT7 | SAR1 CH2 |
| CNT8 | SAR2 CH2 |
| CNT9 | SAR0 CH3 |
| CNT10 | SAR1 CH3 |
| CNT11 | SAR2 CH3 |

可以看出，它是按 SAR0、SAR1、SAR2 交错排列的。若 PCB 上的电流采样脚没有落在这些固定通道上，就不要硬套一对一方案，改用第 4 节的通用触发广播。

---

## 6. ADC 完成以后，FOC 应该在哪里运行

推荐流程：

```text
PWM CC1 事件
  -> ADC 硬件采样
  -> ADC group done
  -> ADC 中断
  -> 读取 Ia、Ib、母线电压等结果
  -> 零偏和比例换算
  -> Clarke
  -> Park
  -> Id/Iq PI
  -> 反 Park
  -> SVPWM
  -> 写入三个 CC0 buffer
  -> 下一个 PWM 周期统一生效
```

中断中可使用当前 SDK 已存在的接口：

```c
Cy_Adc_Channel_GetInterruptMaskedStatus();
Cy_Adc_Channel_GetResult();
Cy_Adc_Channel_ClearInterruptStatus();
```

先选择其中一个 SAR 的最后完成通道作为 FOC 中断源，避免 SAR0、SAR1、SAR2 各进一次中断。进入中断后再检查其他 SAR 的结果有效状态，确保三路数据属于同一个 PWM 周期。

如果采样通道分别位于三个 SAR，它们是真正并行转换；如果多个采样通道都放在同一个 SAR，只能由该 SAR 的序列器依次转换，不是同一时刻采样。

---

## 7. 初始化顺序

建议严格按照下面的顺序配置：

1. 配置系统时钟。
2. 配置 ADC 外设时钟和模拟 GPIO。
3. 初始化 SAR0/SAR1/SAR2。
4. 在 ADC 通道未使能时配置通道参数和硬件触发源。
5. 配置 `Cy_Adc_SetGenericTriggerInput()`。
6. 配置 TriggerMux 路由。
7. 初始化三个中心对齐 PWM 计数器。
8. 修正 CC0/CC1 上下计数匹配使能位。
9. 清除 ADC 和 TCPWM 的旧中断标志。
10. 使能 ADC 通道。
11. 使能 ADC 中断。
12. 使能三个 PWM 计数器，并进行同步启动。

重点是：**先把 ADC 和触发路由全部准备好，最后再启动 PWM。** 否则初始化过程中可能出现一次非预期 ADC 转换或不完整的第一组数据。

---

## 8. 第一阶段调试方法

不要一开始就接完整 FOC 算法，按下面顺序验证：

### 第一步：验证 PWM

- 三相 PWM 频率是否正确。
- 三个中心对齐计数器是否同步。
- 互补输出和死区是否正确。
- 关闭功率级或保持母线低压调试。

### 第二步：验证触发次数

在 ADC 完成中断中翻转一个 GPIO：

- GPIO 频率等于 PWM 频率的一半：每次中断翻转一次，这是正常现象。
- GPIO 频率等于 PWM 频率：可能每周期触发两次，检查 CC1 上下方向使能。
- GPIO 不动：检查 `trigger1EventCfg`、TriggerMux 返回值、ADC `triggerSelection` 和通道使能。

### 第三步：验证采样位置

同时观察：

- PWM 相输出。
- ADC 中断翻转 GPIO。
- 电流采样运放输出。

逐步调整 `FOC_ADC_SAMPLE_COUNT`，让采样时刻避开开关边沿、死区和运放尖峰。

### 第四步：验证数据一致性

- 电机不通电时采集零偏。
- 同一 PWM 周期的多路电流结果必须一起更新。
- 检查 ADC group overflow，若出现说明上一次转换还没处理完又来了新触发。
- 检查 FOC ISR 最坏执行时间必须小于一个 PWM 周期。

---

## 9. 当前工程需要注意的两处 SDK 代码

### 9.1 PWM 初始化没有写入 CC0/CC1 匹配方向使能

文件：`libraries/sdk/common/src/drivers/tcpwm/cy_tcpwm_pwm.c`。

当前 `Cy_Tcpwm_Pwm_Init()` 清零 `workCTRL` 后，没有设置：

```c
u1CC0_MATCH_UP_EN
u1CC0_MATCH_DOWN_EN
u1CC1_MATCH_UP_EN
u1CC1_MATCH_DOWN_EN
```

因此需要在初始化后手动设置，或者后续正式修改 SDK 驱动，使这些选项进入配置结构体。

### 9.2 PWM 初始化计数初值判断使用了 runMode

同一函数中，计数初值的判断代码比较的是 `config->runMode`，从语义上看应当检查 `config->countDirection`。中心对齐模式建议初始化后明确设置计数器初值，并在三相同步启动前确认三个计数器状态一致。

这是当前工程真实存在的代码，不是额外假设出来的 API。

---

## 10. 下一步落地前需要确定的硬件信息

真正写入 `My_TCPWM.c/.h` 前，需要从原理图确定：

1. U、V、W 三相 PWM 和互补 PWM 分别接到哪些管脚。
2. 电流采样是单电阻、双电阻、三电阻还是相线串联传感器。
3. Ia、Ib、Ic 运放输出分别接到 SAR0、SAR1、SAR2 的哪个通道。
4. 是否需要三路真正同时采样。
5. PWM 目标频率、系统给 TCPWM 的实际时钟、死区时间。
6. 电流采样运放的建立时间。

这些信息确定后，再把本文中的 `FOC_PWM_PERIOD_COUNT`、`FOC_ADC_SAMPLE_COUNT`、ADC 通道和 TriggerMux 源通道替换成最终值。

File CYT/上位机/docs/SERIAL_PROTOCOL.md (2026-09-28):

# FOC-UART/1.0 串口协议草案

电脑通过 USB 转串口连接电机驱动板，CAN 继续用于 MCU 之间通信。该文档定义上位机和下位机共同使用的串口帧格式、收发流程和安全状态机。

## 串口配置

- 默认波特率：460800 bit/s
- 数据格式：8-N-1
- 无硬件流控
- 多字节整数和浮点数采用小端序
- 浮点数采用 IEEE 754 单精度格式
- 当前下位机复用 `debug_init()` 的 UART0（P00_1/P00_0），禁止在连接期间混入 `printf` 文本日志

当前阶段默认使用 460800 bit/s 完成控制和调参。基础遥测保持 40 Hz，用于状态卡；示波器通过 `0x17` 订阅全部已勾选的设备字段，下位机使用扩展批次帧返回，采样周期固定为 1 ms。上位机在勾选通道和修改串口配置时，以串口速率的 80% 检查带宽；超额时保留原选择或原配置并提示，不自动降低采样率。已选字段在同一采样点读取，未选字段不进入高速采样和传输。

## 通用帧格式

| 偏移 | 类型 | 字段 |
|---|---|---|
| 0 | `uint8` | 帧头 `0xAA` |
| 1 | `uint8` | 帧头 `0x55` |
| 2 | `uint8` | 协议版本，当前为 1 |
| 3 | `uint8` | 帧类型 |
| 4 | `uint16` | 递增序号 |
| 6 | `uint16` | 负载长度 N，最大 1024 |
| 8 | `uint8[N]` | 负载 |
| 8+N | `uint16` | CRC16-Modbus |

CRC 从版本字段开始计算，到负载最后一个字节结束，不包含 `AA 55` 帧头和 CRC 字段本身。接收端必须按长度取帧，并在 CRC 错误后重新搜索帧头。

## 帧类型

| 类型 | 方向 | 用途 |
|---|---|---|
| `0x01` | 双向 | 握手、固件和能力信息 |
| `0x02` | 双向 | 心跳 |
| `0x10` | 上位机 → 驱动板 | 电机控制命令 |
| `0x11` | 上位机 → 驱动板 | 读取参数 |
| `0x12` | 双向 | 写入参数和回读确认 |
| `0x13` | 上位机 → 驱动板 | 读取 SMO/PLL 参数请求 |
| `0x14` | 双向 | 查询和返回下位机内置乐曲列表 |
| `0x15` | 上位机 → 驱动板 | 编码器零点校准 |
| `0x16` | 上位机 → 驱动板 | 驱动板软件复位 |
| `0x17` | 上位机 → 驱动板 | 配置紧凑观测流字段和请求周期 |
| `0x20` | 驱动板 → 上位机 | 基础遥测 |
| `0x21` | 驱动板 → 上位机 | 可订阅高速波形 |
| `0x22` | 驱动板 → 上位机 | 兼容的 SMO/PLL 固定观测波形 |
| `0x23` | 双向 | 写入 SMO/PLL 参数和回读确认 |
| `0x24` | 驱动板 → 上位机 | 按字段位图排列的紧凑观测流 |
| `0x25` | 驱动板 → 上位机 | 兼容的毫秒时间基准观测批次 |
| `0x26` | 驱动板 → 上位机 | 高分辨率自适应观测批次 |
| `0x27` | 驱动板 → 上位机 | 64 位字段位图扩展观测批次 |
| `0x30` | 驱动板 → 上位机 | 故障事件和快照 |
| `0x31` | 驱动板 → 上位机 | 结构化运行日志 |

## 控制命令负载

`0x10`，16 字节：

| 偏移 | 类型 | 字段 |
|---|---|---|
| 0 | `uint8` | 驱动模式：0 开环、1 编码器 FOC、2 `foc_voice` 音乐 |
| 1 | `uint8` | bit0 使能、bit1 方向/回正方式、bit2 急停 |
| 2 | `uint8` | FOC 子模式：0 电压、1 电流、2 速度、3 位置 |
| 3 | `uint8` | 普通模式保留；音乐模式为曲目编号 |
| 4 | `float32` | 普通模式主目标：开环 Uq、FOC 电流/速度目标绝对值，或位置模式目标机械角度（°） |
| 8 | `float32` | 普通模式次目标：开环 Angle 或 FOC Ud/Id |
| 12 | `uint16` / `float32` | 开环角度步进；FOC 电流模式为电流环带宽（Hz），其后 2 字节保留；FOC 速度模式为速度斜坡速率（rpm/s，范围 1~100000）；位置模式保留 |

速度模式下，界面使用目标转速的正负号表示旋转方向。上位机下发目标转速绝对值和速度斜坡速率，并按照目标符号自动设置方向位。下位机在 1 kHz 速度环中生成斜坡目标，启动以及运行中修改目标转速时均按该速率平滑变化；停止和急停仍立即关闭输出。电机运行时修改速度斜率通过控制帧实时生效，停止时修改则同时通过参数帧写入，确保下一次参数回读保持一致。

## FOC 环路参数

读取参数使用 `0x11`，负载长度为 0。下位机返回 `0x12` 参数负载；上位机写入时也使用相同的 `0x12` 负载布局，长度为 44 字节：

| 偏移 | 类型 | 字段 |
|---|---|---|
| 0 | `uint16` | 电流环带宽，Hz |
| 2 | `uint16` | 保留，写 0 |
| 4 | `float32` | 速度斜坡速率，rpm/s，参数未配置时为 0，配置范围 1~100000 |
| 8 | `float32` | 速度环 KP |
| 12 | `float32` | 速度环 KI |
| 16 | `float32` | 速度环积分项限幅，A，最大 5 A |
| 20 | `float32` | AB 滤波器带宽，Hz，范围 1~500 Hz |
| 24 | `float32` | 位置环 KP |
| 28 | `float32` | 位置环到位线性软化范围，度，范围 0~180，不大于角度死区时关闭 |
| 32 | `float32` | 位置环到位速度死区，rpm，范围 0~100，固件默认 20，写 0 时关闭 |
| 36 | `float32` | 位置环输出限幅，rpm |
| 40 | `float32` | 位置环角度死区，度，范围 0~180 |

下位机校验参数后使用短临界区整组应用，支持在电机运行中调整电流环、速度环和位置环参数。上位机拖动调节控件时按 80 ms 合并连续变化，只发送该时间段内的最新参数。上位机离线时速度斜率保持 0，不预置设备参数；连接后先读取参数，界面以回读结果覆盖离线初值，速度斜率也采用下位机回读值。参数未同步前不得启动有感 FOC。全部有感 FOC 子模式还必须具备有效编码器零点参数，否则下位机拒绝使能并关闭输出。

无感观测器参数使用独立的 `0x13/0x23` 帧，负载长度为 16 字节，按顺序为 `smoKSlide`、`smoBoundaryCurrent`、`smoFilterBandwidth` 和 `pllBandwidth`，全部为 `float32`，两个带宽字段的单位均为 Hz。PLL 阻尼比固定为 `0.707`，下位机将 `pllBandwidth` 作为自然频率，按 `ωn=2π·pllBandwidth`、`Kp=2·0.707·ωn`、`Ki=ωn²` 自动生成 PI 增益；电角速度和积分项限幅为固件固定保护配置，不作为在线调参项。默认 PLL 带宽为 20 Hz，通常从 10~30 Hz 开始，并建议不超过 SMO 反电动势滤波带宽的五分之一。带宽增大时锁定更快但角度和速度噪声更大，带宽减小时输出更平滑但加减速跟随变慢。HFI 当前预留，不发送参数。独立帧保留了原有 44 字节有感参数帧的兼容性。SMO/PLL 参数支持运行中调整；连续调整已有 SMO 参数时保留估算电流，首次启用或停机写入时重新初始化观测器状态。参数当前只写入下位机运行时 RAM，不写 Flash；每次上电先使用固件初始化值，连接同步时上位机以下位机回传值覆盖界面参数。

无感观测模式仍会读取编码器角度并计算 `speedActual`，该值仅作为上位机的实际转速诊断量，用于和 PLL 估算转速对比，不参与无感控制反馈。

电流和速度模式不再单独选择方向，目标值非负时 bit1 为 0，目标值为负时 bit1 为 1；开环和电压模式下 bit1 仍由方向选择控制。位置模式下该位改为回正方式：bit1 为 0 时按最近距离回正，也是上位机默认选项；bit1 为 1 时连续累计位置模式建立参考后的偏转角度，并沿偏转路径的反方向原路回正。例如顺时针偏转 270 度后，原路回正模式会逆时针返回 270 度，最近距离模式则顺时针返回 90 度。

位置环反馈使用扣除编码器零偏并修正编码器方向后的单圈机械角，按 `uint16` 单圈计数线性映射为 `0~360` 度，`360` 度与 `0` 度等价。最近距离误差展开到 `-180~180` 度；原路回正误差通过相邻位置环采样的最短角度增量连续累加，因此跨越 `0/360` 度时不会丢失偏转圈数。误差绝对值不超过角度死区时，位置环输出速度目标为 0；超出死区时先从误差绝对值中扣除死区宽度，得到有效误差。软化范围大于角度死区时，在角度死区边界至软化范围之间，位置 KP 比例按照 `|有效误差| / (软化范围 - 角度死区)` 从 0 线性恢复到完整增益；软化范围小于等于角度死区时关闭软化。

到位速度死区只在位置误差已经进入角度死区后生效。此时若实际转速仍高于速度死区，速度环继续以零速目标制动；实际转速进入速度死区后，清除速度 PI 状态并令 `Iq` 目标为 0，避免编码器零速噪声持续激励电机。位置误差离开角度死区后立即恢复正常位置和速度控制。

速度环 PI 输出由下位机按照 `sqrt(Imax² - Id²)` 计算出的 q 轴可用电流动态限幅，并将饱和误差反算给积分器。AB 滤波器带宽在速度环参数区设置，用于编码器转速反馈滤波。

上位机连接物理串口后以 20 Hz 周期发送该命令，同时兼作控制心跳。急停、停止等状态变化时不应等待下一周期，应立即额外发送一帧。

音乐模式不再使用单频频率和幅值参数。驱动模式为 2 时，偏移 3 为通过 `0x14` 乐曲列表获得的曲目编号；偏移 4 改按 `uint32` 解释为播放会话号，偏移 8 和 12 置零。上位机每次按下播放按钮都递增会话号。下位机仅在使能由关闭变为打开、曲目编号改变或收到新的会话号时从头播放；20 Hz 心跳中的相同会话号只能保活，不得重新触发曲目。乐曲节拍和播放过程全部由下位机负责，上位机不计算播放进度。

## 零点校准命令

`0x15`，负载长度为 0。下位机收到合法帧后先停止当前控制输出，再在主循环中执行桥臂自检和编码器零点校准。该命令是一次性触发命令，不随控制心跳重复发送；上位机仅允许在设备已连接、电机未运行且急停未锁定时发送。

## 驱动板软件复位命令

`0x16`，负载长度为 0。下位机收到合法帧后先停止控制输出，再触发 CM4 系统软件复位；对当前 CM4 电机控制应用等效于按键重新启动，复位原因记录为软件复位。该命令不会修改 Flash 中保存的电机参数。上位机发送复位前必须先发送失能控制帧，避免驱动板重启后因控制心跳残留自动重新启动电机。

## 内置乐曲列表

上位机打开物理串口后发送一帧负载长度为 0 的 `0x14` 查询。下位机按曲目编号顺序逐首返回 `0x14` 响应，每首乐曲占一帧：

| 偏移 | 类型 | 字段 |
|---|---|---|
| 0 | `uint8` | 曲目编号，从 1 开始连续编号 |
| 1 | `uint8` | 下位机内置曲目总数 |
| 2 | `uint8` | UTF-8 曲名的字节数 M，当前最大 48 |
| 3 | `uint8[M]` | UTF-8 编码曲名，不带结尾 `\0` |

同一次查询的全部响应必须携带相同的曲目总数。上位机收齐全部编号后才一次性替换乐曲下拉列表；未收到响应或响应不完整时继续显示兼容列表。因此以后新增下位机曲目时，只需在下位机音乐表中维护曲名和旋律，上位机在重新连接后会自动同步。

## 基础遥测负载

`0x20`，24 字节。基础遥测只服务于工作台顶部四个状态卡，其余示波器字段必须通过勾选后的高速观测流发送：

| 偏移 | 类型 | 字段 |
|---|---|---|
| 0 | `uint8` | 电机状态 |
| 1 | `uint8` | 当前控制模式 |
| 2 | `uint8` | 当前最高优先级故障 |
| 3 | `uint8` | 状态标志 |
| 4 | `uint32` | 设备运行时间，ms |
| 8 | `float32` | 实际转速，rpm |
| 12 | `float32` | 实际 Iq，A |
| 16 | `float32` | 母线电压，V |
| 20 | `float32` | 校正后的机械角度，°，范围 0~360 |

下位机仍可发送旧版 56 字节基础遥测，上位机保留兼容解码；新版下位机使用 24 字节格式减少固定串口占用。

状态标志中 bit0 表示控制输出使能，bit1 表示电流采样已校准，bit2 表示下位机正在播放音乐，bit3 表示最近一次运行中的停机由控制帧超时触发，bit4 表示本次上电后 UART 软件接收缓冲曾溢出。bit3 在下一次成功使能时清除；bit4 保持到下位机复位，仅能证明发生过软件缓冲溢出，不能单独确定停机原因，也不覆盖 UART 硬件 FIFO 丢字节。旧版固件的 bit3、bit4 均为 0，不能据此排除超时或丢帧。上位机观察到 bit2 从 1 变为 0 后，应立即发送失能控制帧并将播放按钮恢复为待机状态。

### 高速波形负载

`0x21`，36 字节单采样负载：

| 偏移 | 类型 | 字段 |
|---|---|---|
| 0 | `uint32` | 设备运行时间，ms |
| 4 | `float32` | A 相电流，A |
| 8 | `float32` | B 相电流，A |
| 12 | `float32` | C 相电流，A |
| 16 | `float32` | PWM 重构 D 轴电压，V |
| 20 | `float32` | PWM 重构 Q 轴电压，V |
| 24 | `float32` | PWM A，占空比百分比 |
| 28 | `float32` | PWM B，占空比百分比 |
| 32 | `float32` | PWM C，占空比百分比 |

当前上位机连接后发送 13 字节 `0x17` 扩展配置，所有驱动模式都通过 `0x27` 返回当前勾选且不属于顶部四项的字段。高速观测只在控制输出使能后发送，失能状态仅保留基础遥测，避免空载时持续占用串口和界面资源。未收到过 `0x17` 的旧版上位机仍可在开环及音乐模式接收每 10 ms 一帧的 `0x21` 普通波形，在有感及无感 FOC 模式接收每 20 ms 一帧的 `0x22` 兼容观测波形。3/7 字节旧配置继续对应 `0x25` 毫秒批次，8 字节配置继续对应 `0x26` 自适应批次。基础遥测仍按 25 ms 发送，各类帧共用帧序号，接收端应按负载中的设备时间戳排序。

实际 Id/Iq 在控制中断中持续更新并进入高速流；无感模式下使用编码器电角度进行 Park 变换，仅作为诊断数据，不参与无感控制反馈。Ud/Uq 不读取可能停留在旧值的电流环输出缓存，而是根据实时三相 PWM 占空比与母线电压重构：开环模式使用开环电角度，其余模式使用编码器电角度。转矩值使用 1 kHz 缓存结果，采集高速流时不再重复执行估算。

`0x22` SMO/PLL 观测波形负载为 56 字节，字段如下：

| 偏移 | 类型 | 字段 |
|---|---|---|
| 0 | `uint32` | 设备运行时间，ms |
| 4 | `float32` | SMO 估算 Iα，A |
| 8 | `float32` | SMO 估算 Iβ，A |
| 12 | `float32` | SMO 未滤波 Eα，V |
| 16 | `float32` | SMO 未滤波 Eβ，V |
| 20 | `float32` | SMO 滤波 Eα，V |
| 24 | `float32` | SMO 滤波 Eβ，V |
| 28 | `float32` | PLL 估算机械角度，° |
| 32 | `float32` | PLL 估算电角度，° |
| 36 | `float32` | PLL 估算电角速度，rad/s |
| 40 | `float32` | PLL 相位误差，° |
| 44 | `float32` | 实际 Iα，A |
| 48 | `float32` | 实际 Iβ，A |
| 52 | `float32` | SMO Iq 误差（实际 Iq - 估算 Iq），A |

其中角度和相位误差单位为度，电角速度单位为 `rad/s`。PLL 对反电动势正交分量进行幅值归一化鉴相，并根据转向消除正反转的反电动势极性差异；输出角度包含按 SMO 一阶低通带宽和当前估算电角速度计算的动态相位补偿。实际 Iα/Iβ 来自当前采样电流的 Clarke 变换，用于与 SMO 估算电流对比；Iq 误差使用编码器电角度将两组 α/β 电流分别变换到同一 dq 坐标系后计算，定义为实际 Iq 减去估算 Iq。上位机将该帧与普通高速波形合并到同一示波器缓冲区。

### 紧凑观测流

`0x17` 配置帧支持 3 字节、7 字节、8 字节和 13 字节四种负载。当前上位机发送 13 字节格式，以覆盖示波器中的全部设备通道：

| 偏移 | 类型 | 字段 |
|---|---|---|
| 0 | `uint64` | 观测字段位图 |
| 8 | `uint8` | 周期字段，上位机发送 1，下位机对扩展订阅固定使用 1 ms |
| 9 | `uint32` | 兼容保留的带宽字段，上位机发送所选波特率的 80%，扩展订阅不据此降速 |

旧版 3 字节格式如下：

| 偏移 | 类型 | 字段 |
|---|---|---|
| 0 | `uint16` | 观测字段位图 |
| 2 | `uint8` | 请求采样周期，单位为 ms，当前固定为 1 |

7 字节格式在 3 字节格式后增加 `uint32` 可用带宽；8 字节格式使用 `uint16` 控制节拍周期和 `uint32` 可用带宽。三种旧格式供兼容工具使用，仍按以下公式调整实际周期；当前上位机使用的 13 字节扩展订阅固定为 1 ms，不使用此降速规则。位图为 0 时关闭观测高速流，但不影响 `0x20` 基础遥测。

```text
最小周期(控制节拍) = ceil(完整批次帧字节数 × 10 × 20000
                            / (可用带宽 × 单帧采样数))
```

所有已勾选的设备通道均进入 1 ms 高速流，包括实际转速、实际 Iq、母线电压、机械角度和 PLL 角度。默认 460800 bit/s、8-N-1 和 80% 带宽预算下，上位机最多允许同时选择 8 个设备通道；全选、模式推荐、单通道切换以及串口配置修改均检查此限制。目标机械角由上位机生成，不占设备通道带宽。带宽检查使用实际批次点数，不能假定所有批次都能装满 8 点：

```text
批次点数 = min(8, floor((256 - 14) / (4 × 设备通道数)))
所需带宽 = (10 + 14 + 4 × 设备通道数 × 批次点数) × 每字节串口位数 × 1000 / 批次点数
```

连接有效且存在订阅时，电机失能也继续采集和发送；控制通信超时则暂停观测流。切换订阅后，以当前设备时间重新建立采样时基。基础遥测不填充已选设备通道的示波器曲线；高速流中断超过 200 ms 后仅让状态卡恢复基础遥测。此规则需要同步更新下位机固件，旧固件缺失的高速字段不再用低速数据冒充。

字段位图定义如下：

| 位 | 观测字段 | 单位 |
|---|---|---|
| bit0 | 实际 Iα | A |
| bit1 | 实际 Iβ | A |
| bit2 | SMO 估算 Iα | A |
| bit3 | SMO 估算 Iβ | A |
| bit4 | SMO Iq 误差（实际 - 估算） | A |
| bit5 | SMO 未滤波 Eα | V |
| bit6 | SMO 未滤波 Eβ | V |
| bit7 | SMO 滤波 Eα | V |
| bit8 | SMO 滤波 Eβ | V |
| bit9 | 编码器实际电角度 | ° |
| bit10 | PLL 估算电角度 | ° |
| bit11 | PLL 估算电角速度 | rad/s |
| bit12 | PLL 相位误差 | ° |
| bit13 | PLL 估算机械角度 | ° |
| bit14 | 编码器实际机械转速 | rpm |
| bit15 | 编码器实际机械角度 | ° |
| bit16 | 目标机械转速 | rpm |
| bit17 | 目标 Id | A |
| bit18 | 实际 Id | A |
| bit19 | 目标 Iq | A |
| bit20 | 实际 Iq | A |
| bit21 | A 相电流 | A |
| bit22 | B 相电流 | A |
| bit23 | C 相电流 | A |
| bit24 | U 相 ADC 原始值 | 计数 |
| bit25 | W 相 ADC 原始值 | 计数 |
| bit26 | PWM 重构 D 轴电压 | V |
| bit27 | PWM 重构 Q 轴电压 | V |
| bit28 | 母线电压 | V |
| bit29 | PWM A 占空比 | % |
| bit30 | PWM B 占空比 | % |
| bit31 | PWM C 占空比 | % |
| bit32 | 编码器零点偏移 | 计数 |
| bit33 | 估算转矩 | N·m |

字段始终按 bit0 到 bit33 的顺序紧密排列。目标机械角由上位机控制命令生成，不占用下位机订阅位。`0x24` 是旧版单点紧凑帧，只支持 bit0 到 bit15，负载前 6 字节为毫秒时间戳和字段位图：

| 偏移 | 类型 | 字段 |
|---|---|---|
| 0 | `uint32` | 设备运行时间，ms |
| 4 | `uint16` | 本帧实际字段位图 |
| 6 | `float32[]` | 已选字段值，按位号升序排列 |

`0x25`为兼容的毫秒批次帧，固定负载依次为`uint32`基础时间戳、`uint16`字段位图、`uint8`周期毫秒数和`uint8`采样数，随后排列连续采样值。

`0x26`为高分辨率自适应批次帧，固定负载如下：

| 偏移 | 类型 | 字段 |
|---|---|---|
| 0 | `uint32` | 第一组采样的20 kHz时间戳 |
| 4 | `uint16` | 本帧实际字段位图 |
| 6 | `uint16` | 相邻采样周期，单位为20 kHz控制节拍 |
| 8 | `uint8` | 本帧连续采样数 |
| 9 | `float32[]` | 各采样的已选字段值 |

`0x27` 为当前上位机使用的扩展毫秒批次帧，固定负载如下：

| 偏移 | 类型 | 字段 |
|---|---|---|
| 0 | `uint32` | 第一组采样的设备毫秒时间戳 |
| 4 | `uint64` | 本帧实际字段位图 |
| 12 | `uint8` | 相邻采样周期，单位为 ms |
| 13 | `uint8` | 本帧连续采样数 |
| 14 | `float32[]` | 各采样的已选字段值 |

单帧最多合并 8 组采样，负载最长 256 字节。全部已选设备字段在下位机同一采样点内读取，其中转速和估算转矩读取各自的 1 kHz 缓存结果。上位机对已收到高速样本的订阅字段忽略基础遥测中的重复值，避免不同采样时刻的数据交替覆盖；串口和 IPC 分批只影响到达上位机的延迟，不改变设备时间戳及相邻点的真实 1 ms 间隔。

## 下位机安全要求

- 连续 200 ms 未收到合法控制帧时关闭 PWM
- CRC、长度或协议版本错误的帧不得执行
- 急停优先级高于其他所有命令
- 参数范围必须由下位机再次检查
- PWM 频率、死区、极对数等参数只允许在电机失能时修改
- 接收中断只负责写入环形缓冲区，解析和命令处理放在主循环或低优先级任务
- FOC 电流环中断只写遥测缓冲区，不直接阻塞发送串口数据

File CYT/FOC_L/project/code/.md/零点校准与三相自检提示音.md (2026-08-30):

# 零点校准与三相自检提示音说明

执行零点校准时，驱动板会先进行三相桥臂鸣响自检，然后执行编码器零点校准和参数保存。各组声音含义如下。

| 听到的声音 | 含义 |
|---|---|
| C5 一声 | A 相桥臂自检 |
| E5 两声 | B 相桥臂自检 |
| G5 三声 | C 相桥臂自检 |
| D5、E5、F5、G5、A5、B5、C6 快速上升七音阶 | 编码器零点校准成功，编码器方向、极对数和机械零偏已得到有效结果 |
| C6、B5、A5、G5、F5、E5、D5 快速下降七音阶 | 校准参数已成功保存到 Flash |

## 结果判断

- 正常完成时，应先听到一声、两声、三声三组桥臂自检音，然后听到上升七音阶和下降七音阶。
- 某组桥臂自检音缺失、明显偏弱或异常时，应停止校准并检查对应相的 MOS、预驱、相线和供电。
- 三相自检完成后没有上升七音阶，表示本次零点校准没有成功，不能认为当前零点参数有效。
- 听到上升七音阶但没有下降七音阶，表示零点校准成功，但参数没有成功保存到 Flash，重新上电后可能丢失。

三相自检采用人工听音判断，不会自动检测并上报某一相通过或失败。

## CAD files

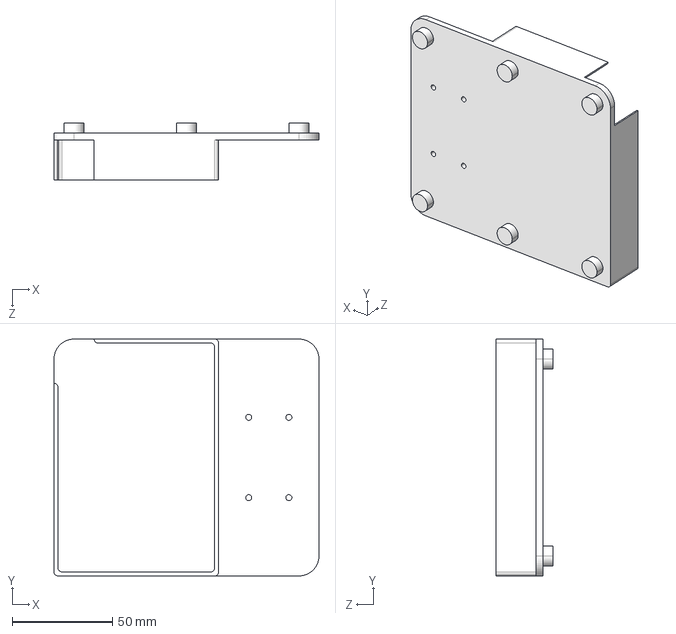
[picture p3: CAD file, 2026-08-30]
CYT/电机调试台/底座.STEP
132.0 x 118.0 x 28.5 mm

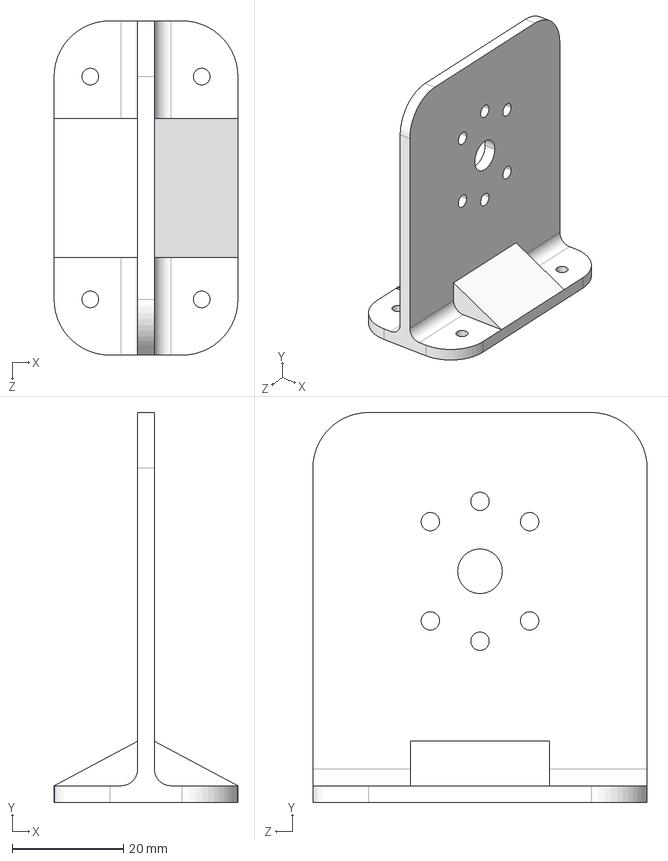
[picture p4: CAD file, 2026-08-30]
CYT/电机调试台/支座.STEP
33.0 x 70.0 x 60.0 mm

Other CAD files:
CYT/电机调试台/底座.SLDPRT
CYT/电机调试台/底座.STL
CYT/电机调试台/支座.SLDPRT
CYT/电机调试台/支座.STL

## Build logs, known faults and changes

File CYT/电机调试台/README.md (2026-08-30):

# 电机调试台

电机调试台成品

本目录包含电机调试台底座和支座的 SolidWorks、STEP、STL 模型，以及实际装配完成后的成品照片。

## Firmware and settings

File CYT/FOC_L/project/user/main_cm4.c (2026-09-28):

/*********************************************************************************************************************
* CYT2BL3 Opensourec Library 即（ CYT2BL3 开源库）是一个基于官方 SDK 接口的第三方开源库
* Copyright (c) 2022 SEEKFREE 逐飞科技
*
* 本文件是 CYT2BL3 开源库的一部分
*
* CYT2BL3 开源库 是免费软件
* 您可以根据自由软件基金会发布的 GPL（GNU General Public License，即 GNU通用公共许可证）的条款
* 即 GPL 的第3版（即 GPL3.0）或（您选择的）任何后来的版本，重新发布和/或修改它
*
* 本开源库的发布是希望它能发挥作用，但并未对其作任何的保证
* 甚至没有隐含的适销性或适合特定用途的保证
* 更多细节请参见 GPL
*
* 您应该在收到本开源库的同时收到一份 GPL 的副本
* 如果没有，请参阅<https://www.gnu.org/licenses/>
*
* 额外注明：
* 本开源库使用 GPL3.0 开源许可证协议 以上许可申明为译文版本
* 许可申明英文版在 libraries/doc 文件夹下的 GPL3_permission_statement.txt 文件中
* 许可证副本在 libraries 文件夹下 即该文件夹下的 LICENSE 文件
* 欢迎各位使用并传播本程序 但修改内容时必须保留逐飞科技的版权声明（即本声明）
*
* 文件名称          main_cm4
* 公司名称          成都逐飞科技有限公司
* 版本信息          查看 libraries/doc 文件夹内 version 文件 版本说明
* 开发环境          IAR 9.40.1
* 适用平台          CYT2BL3
* 店铺链接          https://seekfree.taobao.com/
*
* 修改记录
* 日期              作者                备注
* 2024-11-19       pudding            first version
********************************************************************************************************************/

#include "My_Headfile.h"

// 打开新的工程或者工程移动了位置务必执行以下操作
// 第一步 关闭上面所有打开的文件
// 第二步 project->clean  等待下方进度条走完

// 本例程是开源库空工程 可用作移植或者测试各类内外设
// 本例程是开源库空工程 可用作移植或者测试各类内外设
// 本例程是开源库空工程 可用作移植或者测试各类内外设

// **************************** 代码区域 ****************************

int main(void)
{
    clock_init(SYSTEM_CLOCK_160M);      // 时钟配置及系统初始化<务必保留>
    
    Foc_Protocol_Init();                // 初始化调试串口及上位机协议

    My_LED_Init();                      // LED初始化

    Motor_Control_Init();               // 初始化编码器及FOC控制参数

    Motor_Flash_Init();                 // 初始化Flash并恢复电机零点参数

    My_TCPWM_Init();                    // 三相互补PWM及ADC触发源初始化

    My_ADC_Init();                      // 初始化电流采样及母线电压ADC

    pit_ms_init(PIT_CH2, 1);            // 1ms  
    pit_ms_init(PIT_CH11,10);           // 10ms  

    My_TCPWM_Start();                   // 所有模块就绪后启动PWM及ADC触发

    // 此处编写用户代码 例如外设初始化代码等
    for(;;)
    {
        Foc_Protocol_Service();          // 主循环处理串口接收和遥测发送
        
    }
}

// **************************** 代码区域 ****************************

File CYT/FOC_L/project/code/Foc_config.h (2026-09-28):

#ifndef FOC_CONFIG_H_
#define FOC_CONFIG_H_

/*===========================================================================*/
/*  控制环调度参数                                                           */
/*===========================================================================*/
#define MOTOR_CURRENT_LOOP_HZ           (20000u)    /* 电流环执行频率，单位为Hz */
#define MOTOR_SPEED_LOOP_HZ             (1000u)     /* 速度环执行频率，单位为Hz */
#define MOTOR_POSITION_LOOP_HZ          (500u)      /* 位置环执行频率，单位为Hz */
#define MOTOR_VOICE_LOOP_HZ             MOTOR_CURRENT_LOOP_HZ    /* 电机音乐控制频率，单位为Hz */
#define MOTOR_OBSERVER_TIMEBASE_HZ      MOTOR_CURRENT_LOOP_HZ    /* 观测采样时基频率，单位为Hz */
#define MOTOR_OBSERVER_STREAM_MAX_HZ    (4000u)     /* 观测流最高采样频率，单位为Hz */
#define MOTOR_OBSERVER_STREAM_MIN_HZ    (50u)       /* 观测流最低采样频率，单位为Hz */

#define PID_BANDWIDTH_MIN_HZ            (1u)        /* 电流环带宽下限，单位为Hz */
#define PID_BANDWIDTH_MAX_HZ            (5000u)     /* 电流环带宽上限，单位为Hz */

#if ((MOTOR_CURRENT_LOOP_HZ == 0u) || \
     (MOTOR_SPEED_LOOP_HZ == 0u) || \
     (MOTOR_POSITION_LOOP_HZ == 0u) || \
     (MOTOR_OBSERVER_STREAM_MAX_HZ == 0u) || \
     (MOTOR_OBSERVER_STREAM_MIN_HZ == 0u))
#error "控制环及观测流频率必须大于0"
#else
#if ((MOTOR_CURRENT_LOOP_HZ % MOTOR_SPEED_LOOP_HZ) != 0u)
#error "电流环频率必须能被速度环频率整除"
#endif

#if ((MOTOR_CURRENT_LOOP_HZ % MOTOR_POSITION_LOOP_HZ) != 0u)
#error "电流环频率必须能被位置环频率整除"
#endif

#if ((MOTOR_OBSERVER_TIMEBASE_HZ % 1000u) != 0u)
#error "观测采样时基频率必须能被1 kHz整除"
#endif

#if (MOTOR_OBSERVER_STREAM_MIN_HZ > MOTOR_OBSERVER_STREAM_MAX_HZ)
#error "观测流最低采样频率不能高于最高采样频率"
#endif

#if ((MOTOR_OBSERVER_TIMEBASE_HZ % MOTOR_OBSERVER_STREAM_MAX_HZ) != 0u)
#error "观测采样时基频率必须能被观测流最高采样频率整除"
#endif

#if ((MOTOR_OBSERVER_TIMEBASE_HZ % MOTOR_OBSERVER_STREAM_MIN_HZ) != 0u)
#error "观测采样时基频率必须能被观测流最低采样频率整除"
#endif
#endif

#define MOTOR_SPEED_LOOP_DIVIDER        \
    (MOTOR_CURRENT_LOOP_HZ / MOTOR_SPEED_LOOP_HZ)       /* 速度环相对电流环的分频系数 */
#define MOTOR_POSITION_LOOP_DIVIDER     \
    (MOTOR_CURRENT_LOOP_HZ / MOTOR_POSITION_LOOP_HZ)    /* 位置环相对电流环的分频系数 */
#define MOTOR_OBSERVER_TICKS_PER_MS     \
    (MOTOR_OBSERVER_TIMEBASE_HZ / 1000u)                /* 每毫秒包含的观测采样节拍数 */
#define MOTOR_OBSERVER_PERIOD_MIN_TICK  \
    (MOTOR_OBSERVER_TIMEBASE_HZ / MOTOR_OBSERVER_STREAM_MAX_HZ) /* 观测流最短采样周期 */
#define MOTOR_OBSERVER_PERIOD_MAX_TICK  \
    (MOTOR_OBSERVER_TIMEBASE_HZ / MOTOR_OBSERVER_STREAM_MIN_HZ) /* 观测流最长采样周期 */
#define MOTOR_CURRENT_LOOP_TS           \
    (1.0f / (float)MOTOR_CURRENT_LOOP_HZ)               /* 电流环采样周期，单位为秒 */
#define MOTOR_SPEED_LOOP_TS             \
    (1.0f / (float)MOTOR_SPEED_LOOP_HZ)                 /* 速度环采样周期，单位为秒 */
#define MOTOR_POSITION_LOOP_TS          \
    (1.0f / (float)MOTOR_POSITION_LOOP_HZ)              /* 位置环采样周期，单位为秒 */

/*===========================================================================*/
/*  电流控制限幅参数                                                         */
/*===========================================================================*/
#define MOTOR_CURRENT_VECTOR_LIMIT_A    (10.0f)        /* d/q轴电流矢量固定限幅，单位为A */

/*===========================================================================*/
/*  AB滤波器参数                                                             */
/*===========================================================================*/
#define MOTOR_AB_FILTER_BW_MIN_HZ       (1.0f)         /* AB滤波器带宽下限，单位为Hz */
#define MOTOR_AB_FILTER_BW_MAX_HZ       (500.0f)       /* AB滤波器带宽上限，单位为Hz */

/*===========================================================================*/
/*  SMO参数                                                                  */
/*===========================================================================*/
#define MOTOR_SMO_FILTER_BW_MIN_HZ      (1.0f)         /* SMO滤波带宽下限，单位为Hz */
#define MOTOR_SMO_FILTER_BW_MAX_HZ      (500.0f)       /* SMO滤波带宽上限，单位为Hz */

/*===========================================================================*/
/*  PLL参数                                                                  */
/*===========================================================================*/
#define MOTOR_PLL_BW_MIN_HZ             (1.0f)         /* PLL带宽下限，单位为Hz */
#define MOTOR_PLL_BW_MAX_HZ             (500.0f)       /* PLL带宽上限，单位为Hz */
#define MOTOR_PLL_EMF_MIN_V             (0.02f)        /* PLL允许鉴相的最小反电动势幅值，单位为V */
#define MOTOR_PLL_DAMPING_RATIO         (0.70710678f)  /* PLL固定阻尼比 */
#define MOTOR_PLL_OMEGA_LIMIT_RAD_S     (3000.0f)      /* PLL固定电角速度限幅，单位为rad/s */
#define MOTOR_PLL_INTEGRAL_LIMIT_RAD_S  (3000.0f)      /* PLL固定积分项限幅，单位为rad/s */

/*===========================================================================*/
/*  电机与FOC控制参数                                                        */
/*===========================================================================*/
#define LD              (0.031036f)            /* d轴电感，单位为mH */
#define LQ              (0.035016f)            /* q轴电感，单位为mH */
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

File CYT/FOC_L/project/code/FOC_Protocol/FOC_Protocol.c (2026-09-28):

#include "Foc_Protocol.h"
#include "Current_sample/Current_sample.h"
#include "Foc_voice/Foc_voice.h"
#include "Motor_Control/Motor_Control.h"
#include "Motor_Torque/Motor_Torque.h"
#include "SVPWM/SVPWM.h"

static Foc_Protocol_t Protocol;
static uint8 Foc_Protocol_Rx_buffer[FOC_PROTOCOL_RX_RING_CAPACITY];
static volatile uint16 Foc_Protocol_Rx_read;
static volatile uint16 Foc_Protocol_Rx_write;
static void Foc_Protocol_SendLoopParameters(void);
static void Foc_Protocol_SendObserverParameters(void);
static void Foc_Protocol_HandleObserverParameterWrite(const uint8 *Payload);
static void Foc_Protocol_SendObserverWaveform(void);
static uint8 Foc_Protocol_CountObserverStreamFields(uint64 Mask);
static uint16 Foc_Protocol_AppendObserverStreamFloat(uint8 *Payload,
                                                     uint16 Offset,
                                                     uint64 Field_mask,
                                                     float Value);
static uint8 Foc_Protocol_SendObserverStreamBatch(void);
static void Foc_Protocol_HandleObserverStreamConfig(const uint8 *Payload,
                                                     uint16 Payload_length);
static void Foc_Protocol_HandleReset(void);

/***********************************************
 * @brief : 根据实时PWM占空比重构当前诊断坐标系中的d/q轴电压
 * @param : 无
 * @return: 按PWM占空比重构的d/q轴电压
 * @date  : 2026-09-23
 * @author: L
 ************************************************/
static Park_t Foc_Protocol_GetAppliedVoltagePark(void)
{
    Clark_t Voltage_clark;
    float Phase_voltage_a;
    float Phase_voltage_b;
    float Phase_voltage_c;
    float Common_voltage;
    uint16 Electrical_angle;

    Phase_voltage_a =
        (float)SVPWM.DutyA * SVPWM.VBUS / (float)SVPWM_DUTY_MAX;
    Phase_voltage_b =
        (float)SVPWM.DutyB * SVPWM.VBUS / (float)SVPWM_DUTY_MAX;
    Phase_voltage_c =
        (float)SVPWM.DutyC * SVPWM.VBUS / (float)SVPWM_DUTY_MAX;
    Common_voltage =
        (Phase_voltage_a + Phase_voltage_b + Phase_voltage_c) / 3.0f;

    Voltage_clark.Alpha = Phase_voltage_a - Common_voltage;
    Voltage_clark.Beta =
        ((Phase_voltage_a - Common_voltage) +
         2.0f * (Phase_voltage_b - Common_voltage)) / SQRT3;
    Electrical_angle =
        (Motor.Control_mode == MOTOR_CONTROL_OPEN_LOOP) ?
        Motor.Open_loop.Angle : Motor.Encoder.Electrical_angle;

    return foc_park_calc(Voltage_clark, Electrical_angle);
}

/***********************************************
 * @brief : 计算实测Iq与SMO估算Iq的差值
 * @param : 无
 * @return: 实测Iq减去SMO估算Iq，单位为A
 * @date  : 2026-09-14
 * @author: L
 ************************************************/
static float Foc_Protocol_CalculateObserverIqError(void)
{
    Clark_t Observer_clark;
    Park_t Actual_park;
    Park_t Observer_park;

    /* 使用同一个编码器电角度，保证实测值与估算值位于相同dq坐标系。 */
    Actual_park = foc_park_calc(
        Current.clark,
        Motor.Encoder.Electrical_angle);

    Observer_clark.Alpha = Motor.SMO.I_alpha_est;
    Observer_clark.Beta = Motor.SMO.I_beta_est;
    Observer_park = foc_park_calc(
        Observer_clark,
        Motor.Encoder.Electrical_angle);

    return Actual_park.Iq - Observer_park.Iq;
}

/***********************************************
 * @brief : 读取小端序16位无符号整数
 * @param : Data 待读取字节地址
 * @return: 16位无符号整数
 * @date  : 2026-08-28
 * @author: L
 ************************************************/
static uint16 Foc_Protocol_ReadU16(const uint8 *Data)
{
    return (uint16)Data[0] |
           (uint16)((uint16)Data[1] << 8u);
}

/***********************************************
 * @brief : 读取小端序单精度浮点数
 * @param : Data 待读取字节地址
 * @return: 单精度浮点数
 * @date  : 2026-08-28
 * @author: L
 ************************************************/
static float Foc_Protocol_ReadFloat(const uint8 *Data)
{
    float Value;

    memcpy(&Value, Data, sizeof(Value));
    return Value;
}

/***********************************************
 * @brief : 读取小端序32位无符号整数
 * @param : Data 待读取字节地址
 * @return: 32位无符号整数
 * @date  : 2026-08-28
 * @author: L
 ************************************************/
static uint32 Foc_Protocol_ReadU32(const uint8 *Data)
{
    return (uint32)Data[0] |
           ((uint32)Data[1] << 8u) |
           ((uint32)Data[2] << 16u) |
           ((uint32)Data[3] << 24u);
}

/***********************************************
 * @brief : 读取小端序64位无符号整数
 * @param : Data 待读取字节地址
 * @return: 64位无符号整数
 * @date  : 2026-09-23
 * @author: L
 ************************************************/
static uint64 Foc_Protocol_ReadU64(const uint8 *Data)
{
    return (uint64)Foc_Protocol_ReadU32(Data) |
           ((uint64)Foc_Protocol_ReadU32(&Data[4]) << 32u);
}

/***********************************************
 * @brief : 写入小端序16位无符号整数
 * @param : Data 待写入字节地址
 * @param : Value 待写入数值
 * @return: 无
 * @date  : 2026-08-28
 * @author: L
 ************************************************/
static void Foc_Protocol_WriteU16(uint8 *Data, uint16 Value)
{
    Data[0] = (uint8)Value;
    Data[1] = (uint8)(Value >> 8u);
}

/***********************************************
 * @brief : 写入小端序32位无符号整数
 * @param : Data 待写入字节地址
 * @param : Value 待写入数值
 * @return: 无
 * @date  : 2026-08-28
 * @author: L
 ************************************************/
static void Foc_Protocol_WriteU32(uint8 *Data, uint32 Value)
{
    Data[0] = (uint8)Value;
    Data[1] = (uint8)(Value >> 8u);
    Data[2] = (uint8)(Value >> 16u);
    Data[3] = (uint8)(Value >> 24u);
}

/***********************************************
 * @brief : 写入小端序64位无符号整数
 * @param : Data 待写入字节地址
 * @param : Value 待写入数值
 * @return: 无
 * @date  : 2026-09-23
 * @author: L
 ************************************************/
static void Foc_Protocol_WriteU64(uint8 *Data, uint64 Value)
{
    Foc_Protocol_WriteU32(Data, (uint32)Value);
    Foc_Protocol_WriteU32(&Data[4], (uint32)(Value >> 32u));
}

/***********************************************
 * @brief : 写入小端序单精度浮点数
 * @param : Data 待写入字节地址
 * @param : Value 待写入数值
 * @return: 无
 * @date  : 2026-08-28
 * @author: L
 ************************************************/
static void Foc_Protocol_WriteFloat(uint8 *Data, float Value)
{
    memcpy(Data, &Value, sizeof(Value));
}

/***********************************************
 * @brief : 计算CRC16-Modbus校验值
 * @param : Data 待校验数据地址
 * @param : Length 待校验数据长度
 * @return: CRC16-Modbus校验值
 * @date  : 2026-08-28
 * @author: L
 ************************************************/
static uint16 Foc_Protocol_Crc16(const uint8 *Data, uint16 Length)
{
    uint16 Crc = 0xffffu;
    uint16 Index;
    uint8 Bit_index;

    for (Index = 0u; Index < Length; Index++)
    {
        Crc ^= Data[Index];
        for (Bit_index = 0u; Bit_index < 8u; Bit_index++)
        {
            if ((Crc & 0x0001u) != 0u)
            {
                Crc = (uint16)((Crc >> 1u) ^ 0xa001u);
            }
            else
            {
                Crc >>= 1u;
            }
        }
    }

    return Crc;
}
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

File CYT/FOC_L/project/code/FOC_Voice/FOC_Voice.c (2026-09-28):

#include "Foc_voice.h"
#include "Fast_sin/Fast_sin.h"
#include "Foc_config.h"
#include "Function/Function.h"
#include "Motor_Control/Motor_Control.h"
#include "My_TCPWM/My_TCPWM.h"
#include "SVPWM/SVPWM.h"

/*===========================================================================*/
/*  《奇迹再现》主歌，1=A                                                     */
/*===========================================================================*/
static const Foc_voiceNote_t Miracle_verse[] =
{
    /* 第1~4小节 */
    {FOC_VOICE_PITCH_REST, 2u}, {FOC_VOICE_PITCH_A4, 1u},
    {FOC_VOICE_PITCH_FS4, 1u},  {FOC_VOICE_PITCH_GS4, 1u},
    {FOC_VOICE_PITCH_A4, 1u},   {FOC_VOICE_PITCH_REST, 2u},
    {FOC_VOICE_PITCH_B4, 2u},   {FOC_VOICE_PITCH_A4, 1u},
    {FOC_VOICE_PITCH_GS4, 1u},  {FOC_VOICE_PITCH_GS4, 1u},
    {FOC_VOICE_PITCH_A4, 3u},
    {FOC_VOICE_PITCH_REST, 2u}, {FOC_VOICE_PITCH_A4, 1u},
    {FOC_VOICE_PITCH_FS4, 1u},  {FOC_VOICE_PITCH_GS4, 1u},
    {FOC_VOICE_PITCH_A4, 1u},   {FOC_VOICE_PITCH_REST, 2u},
    {FOC_VOICE_PITCH_CS5, 2u},  {FOC_VOICE_PITCH_B4, 1u},
    {FOC_VOICE_PITCH_B4, 1u},   {FOC_VOICE_PITCH_B4, 1u},
    {FOC_VOICE_PITCH_CS5, 3u},

    /* 第5~8小节 */
    {FOC_VOICE_PITCH_REST, 2u}, {FOC_VOICE_PITCH_A4, 1u},
    {FOC_VOICE_PITCH_FS4, 1u},  {FOC_VOICE_PITCH_GS4, 1u},
    {FOC_VOICE_PITCH_A4, 1u},   {FOC_VOICE_PITCH_REST, 2u},
    {FOC_VOICE_PITCH_CS5, 2u},  {FOC_VOICE_PITCH_A4, 1u},
    {FOC_VOICE_PITCH_A4, 1u},   {FOC_VOICE_PITCH_A4, 1u},
    {FOC_VOICE_PITCH_B4, 3u},
    {FOC_VOICE_PITCH_GS4, 8u},
    {FOC_VOICE_PITCH_F5, 1u},   {FOC_VOICE_PITCH_C5, 1u},
    {FOC_VOICE_PITCH_CS5, 1u},  {FOC_VOICE_PITCH_G5, 1u},
    {FOC_VOICE_PITCH_GS4, 1u},  {FOC_VOICE_PITCH_CS5, 1u},
    {FOC_VOICE_PITCH_FS5, 1u},  {FOC_VOICE_PITCH_FS5, 1u},

    /* 第9~12小节 */
    {FOC_VOICE_PITCH_REST, 2u}, {FOC_VOICE_PITCH_A4, 1u},
    {FOC_VOICE_PITCH_FS4, 1u},  {FOC_VOICE_PITCH_GS4, 1u},
    {FOC_VOICE_PITCH_A4, 1u},   {FOC_VOICE_PITCH_REST, 2u},
    {FOC_VOICE_PITCH_B4, 2u},   {FOC_VOICE_PITCH_A4, 1u},
    {FOC_VOICE_PITCH_GS4, 1u},  {FOC_VOICE_PITCH_GS4, 1u},
    {FOC_VOICE_PITCH_A4, 3u},
    {FOC_VOICE_PITCH_REST, 2u}, {FOC_VOICE_PITCH_A4, 1u},
    {FOC_VOICE_PITCH_FS4, 1u},  {FOC_VOICE_PITCH_GS4, 1u},
    {FOC_VOICE_PITCH_A4, 1u},   {FOC_VOICE_PITCH_REST, 2u},
    {FOC_VOICE_PITCH_CS5, 2u},  {FOC_VOICE_PITCH_B4, 1u},
    {FOC_VOICE_PITCH_B4, 1u},   {FOC_VOICE_PITCH_B4, 1u},
    {FOC_VOICE_PITCH_CS5, 3u},

    /* 第13~16小节 */
    {FOC_VOICE_PITCH_REST, 2u}, {FOC_VOICE_PITCH_A4, 1u},
    {FOC_VOICE_PITCH_FS4, 1u},  {FOC_VOICE_PITCH_GS4, 1u},
    {FOC_VOICE_PITCH_A4, 1u},   {FOC_VOICE_PITCH_REST, 2u},
    {FOC_VOICE_PITCH_CS5, 2u},  {FOC_VOICE_PITCH_A4, 1u},
    {FOC_VOICE_PITCH_A4, 1u},   {FOC_VOICE_PITCH_A4, 1u},
    {FOC_VOICE_PITCH_B4, 3u},
    {FOC_VOICE_PITCH_GS4, 2u},  {FOC_VOICE_PITCH_E5, 1u},
    {FOC_VOICE_PITCH_B4, 1u},   {FOC_VOICE_PITCH_FS5, 1u},
    {FOC_VOICE_PITCH_B4, 1u},   {FOC_VOICE_PITCH_CS6, 2u},
    {FOC_VOICE_PITCH_CS6, 6u},  {FOC_VOICE_PITCH_CS4, 1u},
    {FOC_VOICE_PITCH_DS4, 1u}
};

static const Foc_voiceSection_t Miracle_song[] =
{
    {Miracle_verse, (uint16)(sizeof(Miracle_verse) / sizeof(Miracle_verse[0]))}
};

/*===========================================================================*/
/*  《小星星》旋律                                                            */
/*===========================================================================*/
static const Foc_voiceNote_t Twinkle_verse[] =
{
    {FOC_VOICE_PITCH_C4, 2u}, {FOC_VOICE_PITCH_C4, 2u},
    {FOC_VOICE_PITCH_G4, 2u}, {FOC_VOICE_PITCH_G4, 2u},
    {FOC_VOICE_PITCH_A4, 2u}, {FOC_VOICE_PITCH_A4, 2u},
    {FOC_VOICE_PITCH_G4, 4u},
    {FOC_VOICE_PITCH_F4, 2u}, {FOC_VOICE_PITCH_F4, 2u},
    {FOC_VOICE_PITCH_E4, 2u}, {FOC_VOICE_PITCH_E4, 2u},
    {FOC_VOICE_PITCH_D4, 2u}, {FOC_VOICE_PITCH_D4, 2u},
    {FOC_VOICE_PITCH_C4, 4u},
    {FOC_VOICE_PITCH_G4, 2u}, {FOC_VOICE_PITCH_G4, 2u},
    {FOC_VOICE_PITCH_F4, 2u}, {FOC_VOICE_PITCH_F4, 2u},
    {FOC_VOICE_PITCH_E4, 2u}, {FOC_VOICE_PITCH_E4, 2u},
    {FOC_VOICE_PITCH_D4, 4u},
    {FOC_VOICE_PITCH_G4, 2u}, {FOC_VOICE_PITCH_G4, 2u},
    {FOC_VOICE_PITCH_F4, 2u}, {FOC_VOICE_PITCH_F4, 2u},
    {FOC_VOICE_PITCH_E4, 2u}, {FOC_VOICE_PITCH_E4, 2u},
    {FOC_VOICE_PITCH_D4, 4u},
    {FOC_VOICE_PITCH_C4, 2u}, {FOC_VOICE_PITCH_C4, 2u},
    {FOC_VOICE_PITCH_G4, 2u}, {FOC_VOICE_PITCH_G4, 2u},
    {FOC_VOICE_PITCH_A4, 2u}, {FOC_VOICE_PITCH_A4, 2u},
    {FOC_VOICE_PITCH_G4, 4u},
    {FOC_VOICE_PITCH_F4, 2u}, {FOC_VOICE_PITCH_F4, 2u},
    {FOC_VOICE_PITCH_E4, 2u}, {FOC_VOICE_PITCH_E4, 2u},
    {FOC_VOICE_PITCH_D4, 2u}, {FOC_VOICE_PITCH_D4, 2u},
    {FOC_VOICE_PITCH_C4, 4u}
};

static const Foc_voiceSection_t Twinkle_song[] =
{
    {Twinkle_verse, (uint16)(sizeof(Twinkle_verse) / sizeof(Twinkle_verse[0]))}
};

/*===========================================================================*/
/*  《欢乐颂》旋律                                                            */
/*===========================================================================*/
static const Foc_voiceNote_t Ode_verse[] =
{
    {FOC_VOICE_PITCH_E4, 2u}, {FOC_VOICE_PITCH_E4, 2u},
    {FOC_VOICE_PITCH_F4, 2u}, {FOC_VOICE_PITCH_G4, 2u},
    {FOC_VOICE_PITCH_G4, 2u}, {FOC_VOICE_PITCH_F4, 2u},
    {FOC_VOICE_PITCH_E4, 2u}, {FOC_VOICE_PITCH_D4, 2u},
    {FOC_VOICE_PITCH_C4, 2u}, {FOC_VOICE_PITCH_C4, 2u},
    {FOC_VOICE_PITCH_D4, 2u}, {FOC_VOICE_PITCH_E4, 2u},
    {FOC_VOICE_PITCH_E4, 3u}, {FOC_VOICE_PITCH_D4, 1u},
    {FOC_VOICE_PITCH_D4, 4u},
    {FOC_VOICE_PITCH_E4, 2u}, {FOC_VOICE_PITCH_E4, 2u},
    {FOC_VOICE_PITCH_F4, 2u}, {FOC_VOICE_PITCH_G4, 2u},
    {FOC_VOICE_PITCH_G4, 2u}, {FOC_VOICE_PITCH_F4, 2u},
    {FOC_VOICE_PITCH_E4, 2u}, {FOC_VOICE_PITCH_D4, 2u},
    {FOC_VOICE_PITCH_C4, 2u}, {FOC_VOICE_PITCH_C4, 2u},
    {FOC_VOICE_PITCH_D4, 2u}, {FOC_VOICE_PITCH_E4, 2u},
    {FOC_VOICE_PITCH_D4, 3u}, {FOC_VOICE_PITCH_C4, 1u},
    {FOC_VOICE_PITCH_C4, 4u}
};

static const Foc_voiceSection_t Ode_song[] =
{
    {Ode_verse, (uint16)(sizeof(Ode_verse) / sizeof(Ode_verse[0]))}
};
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

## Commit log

2026-07-24 从头手搓FOC
2026-08-13 单项桥臂GPIO 时钟 TCPWM配置
2026-08-14 TCPWM输出
2026-08-15 三相TCPWM同步触发 SAR ADC配置
2026-08-15 7_0一路ADC数值有问题
2026-08-16 两路adc采样 硬件同步
2026-08-16 adc和tcpwm硬件同步
2026-08-16 adc和逐飞ch10挂一起了 导致毛刺巨大
2026-08-16 TCPWM 和 SARADC 同步触发硬件链路完全打通 噪声20ma
2026-08-17 磁编 电角度 机械角度 SVPWM技术
2026-08-17 三相pwm软同步 零点校准通过
2026-08-17 回滚到TCPWM和SARADC同步触发版本
2026-08-17 Revert "回滚到TCPWM和SARADC同步触发版本"
    This reverts commit ee0856e2433c9ee7efdc3933b2a90a65103b5ed2.
    [Current_sample.c, Current_sample.h, Fast_sin.c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]
2026-08-25 新增零点校准 开环牵引
2026-08-25 硬件触发链路
2026-08-26 位置式PID优化 注释author修改
2026-08-26 新增AB滤波用于解算电机转速
2026-08-26 整改电机结构体参数
2026-08-26 接入ab滤波 测算rpm
2026-08-28 新增电机发声和下位机
2026-08-28 优化下位机
2026-08-28 下位机参数打包成结构体
2026-08-28 优化了下位机和电机发声 删掉了电流的滤波
2026-08-28 新增三相校准 零点校准和音效
2026-08-29 新增falsh 存储成功的发声
2026-08-29 新增三串环
2026-08-29 电流环 速度环参数调整 上位机对齐
2026-08-29 新增扭矩测算 位置环
2026-08-29 有感foc完工
2026-08-29 优化主函数初始化
2026-08-30 下位机传输两相电流采样原始值 修改adc采样点
2026-08-30 添加驱动代码说明文档
2026-08-30 加入上位机PCB和电机调试台工程
    [底座.SLDPRT, 底座.STEP, 底座.STL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]
2026-08-30 补充仓库首页说明
2026-08-30 整理 CYT 整套工程目录
    [底座.SLDPRT, 底座.STEP, 底座.STL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]
2026-08-30 恢复 FOC_L 固件目录结构
    [底座.SLDPRT, 底座.STEP, 底座.STL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]
2026-08-30 补充 FOC_L 完整工程和底层库
2026-08-30 完善README和开源许可证
2026-08-30 添加电机调试台成品照片
2026-08-30 添加零点校准和三相自检提示音说明
2026-08-30 添加上位机讲解视频
2026-08-31 更新开源状态说明
2026-08-31 添加上位机讲解视频链接
2026-09-11 注释规则修改
2026-09-11 注释规范补修
2026-09-11 引入smo估算反电动势
2026-09-13 代码规范修改 无感smo和上位机部分的接入
2026-09-16 无感smo+pll 参数标定 下位机的优化
2026-09-19 删除防御冗余 把pll从smo改到公用接口
2026-09-19 拆分电机功能
2026-09-19 参数整定 分频器引入
2026-09-28 扩展观测数据并优化串口接收保护
2026-09-28 同步上位机观测功能与IAR工程配置
2026-10-06 为上位机添加 Windows 安装包配置
